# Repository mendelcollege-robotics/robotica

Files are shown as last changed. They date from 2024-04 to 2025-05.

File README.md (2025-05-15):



# About
This is the repository for all the files associated with, and used to create, a soccer robot for participation in the [Robocup](https://www.robocup.org/leagues/18). Made by students of the Mendelcollege, from team 'Mendel'.

# Info:

  [Mendelcollege.nl](https://mendelcollege.nl/ontdek-je-talenten/robotica-en-beta/)

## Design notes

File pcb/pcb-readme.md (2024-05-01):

 
teensy data from https://github.com/XenGi/teensy_library

created:
    l298n                   - https://www.kiwi-electronics.com/nl/dual-h-bridge-dc-stepper-motor-driver-l298n-4117?search=l293n
    pololu_motor            - https://www.pololu.com/product/4840
    tssp4038                - https://www.vishay.com/docs/82458/tssp40.pdf
    tcs3472_color_sensor    - https://www.biomaker.org/block-catalogue/2021/12/17/rgb-colour-sensor-tcs34725
    openmv_m7_r2            - https://openmv.io/products/openmv-cam-m7

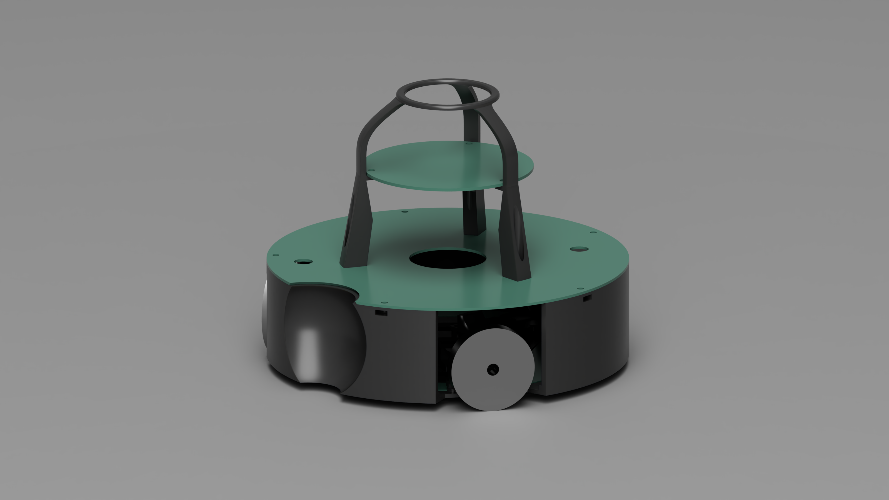
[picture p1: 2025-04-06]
3dfiles/Robot_V3.1_concept_2025-Apr-06_07-42-17PM-000_CustomizedView15199830637.png

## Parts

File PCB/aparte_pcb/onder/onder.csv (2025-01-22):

Id | Aanduiding | Footprint | Hoeveelheid | Orientatie | Leverancier en ref
1 | D11,D7,D9,D2,D5,D1,D10,D3,D8,D12,D4,D6 | LED_RGB_5050-6 | 12 | LED_RGB
2 | PR8,PR4,PR6,PR5,PR2,PR1,PR7,PR3 | FOTORESist | 8 | A1050
3 | 220Ω_36,220Ω_26,220Ω_33,220Ω_8,220Ω_23,220Ω_35,R2,220Ω_24,220Ω_27,220Ω_10,220Ω_4,220Ω_31,220Ω_12,220Ω_21,220Ω_2,10KΩ_4,220Ω_22,220Ω_20,220Ω_19,220Ω_15,220Ω_25,220Ω_17,R3,220Ω_34,10KΩ_6,220Ω_13,220Ω_28,220Ω_16,10KΩ_7,220Ω_7,10KΩ_5,10KΩ_1,220Ω_18,220Ω_6,220Ω_3,220Ω_5,10KΩ_3,220Ω_30,220Ω_11,10KΩ_8,R1,220Ω_14,10KΩ_2,220Ω_1,220Ω_9,220Ω_32,220Ω_29 | R_Axial_DIN0207_L6.3mm_D2.5mm_P10.16mm_Horizontal | 47 | R_US
4 | D13,D14 | D_MELF-RM10_Universal_Handsoldering | 2 | D
5 | J4,J3,J5 | MountingHole_4.3mm_M4_ISO7380_Pad | 3 | Screw_Terminal_01x01
6 | J2 | JST_EH_S10B-EH_1x10_P2.50mm_Horizontal | 1 | Conn_01x10_Socket
7 | Q1,Q3,Q2 | NPN | 3 | NPN
8 | J1 | JST_EH_S4B-EH_1x04_P2.50mm_Horizontal | 1 | Conn_01x04_Socket

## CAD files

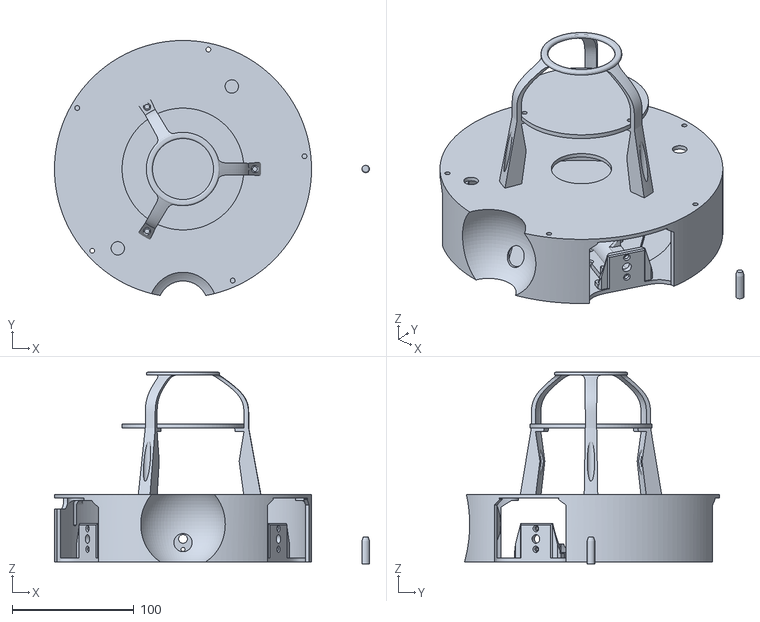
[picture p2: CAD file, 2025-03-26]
3dfiles/oud/Robotica Volledige Robot3 v35.stl
258.6 x 209.3 x 157.5

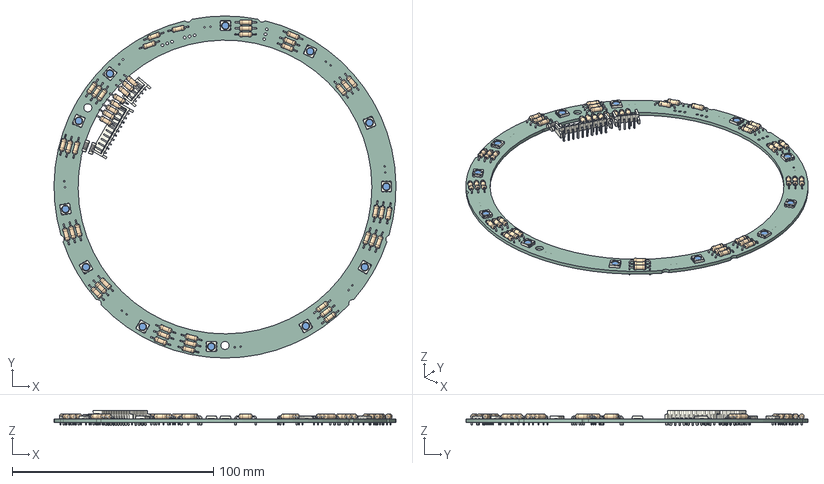
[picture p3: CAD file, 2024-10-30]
PCB/aparte_pcb/onder/onder.step
170.0 x 170.0 x 7.40 mm
LED_RGB_5050_6 x 12
R_Axial_DIN0207_L63mm_D25mm_P1016mm_Horizontal x 47
D_MELF_Standard x 2
JST_S10B_EH
JST_S4B_EH
_autosave-onder_PCB

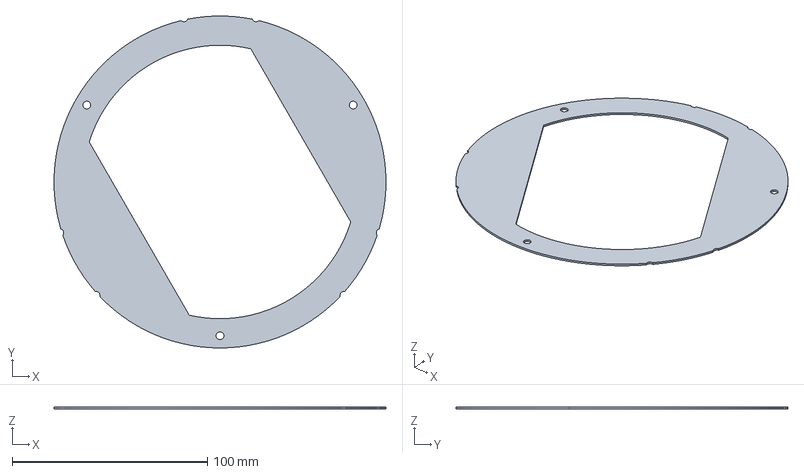
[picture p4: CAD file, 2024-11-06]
3dfiles/oud/PCBondermesh.3mf
170.0 x 170.0 x 1.00 mm

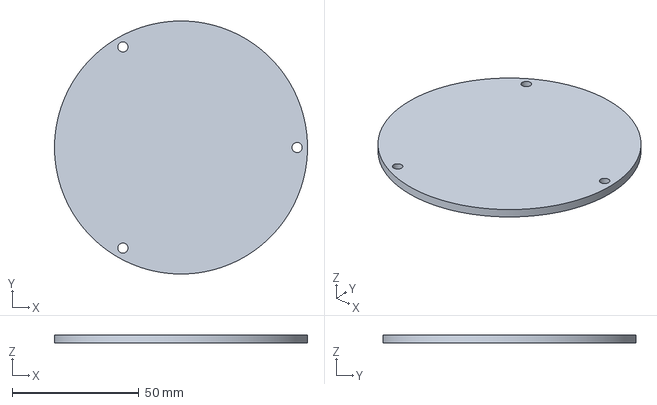
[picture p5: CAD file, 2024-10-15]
3dfiles/oud/PCBboven.3mf
100.0 x 100.0 x 3.25 mm

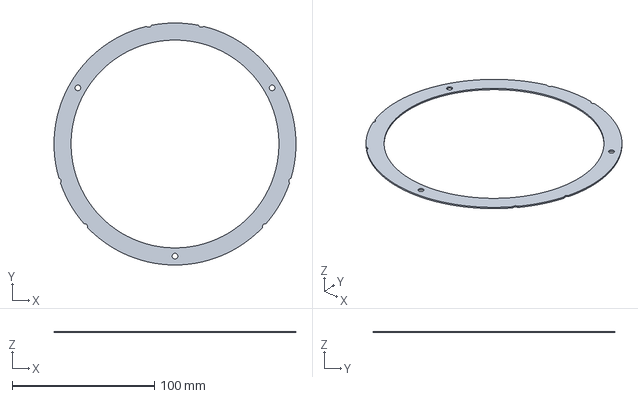
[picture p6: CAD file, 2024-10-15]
3dfiles/oud/PCBonder.3mf
170.0 x 170.0 x 1.00 mm

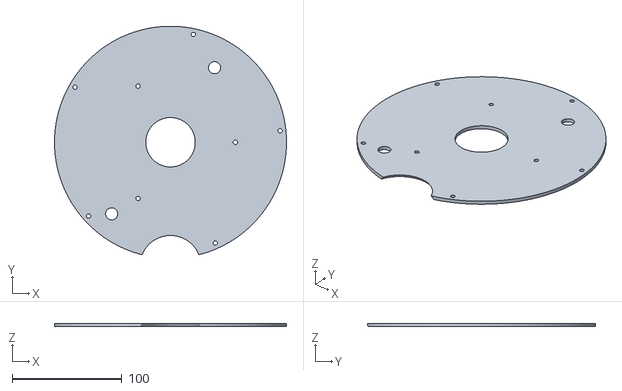
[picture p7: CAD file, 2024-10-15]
3dfiles/oud/PCBmidden.stl
211.0 x 207.8 x 3.00

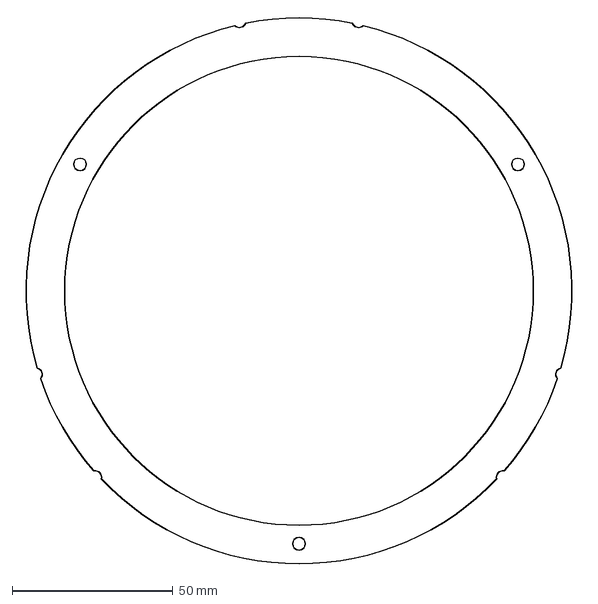
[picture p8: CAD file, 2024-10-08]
3dfiles/oud/pcb_onder(oud).dxf
176.2 x 170.5 mm

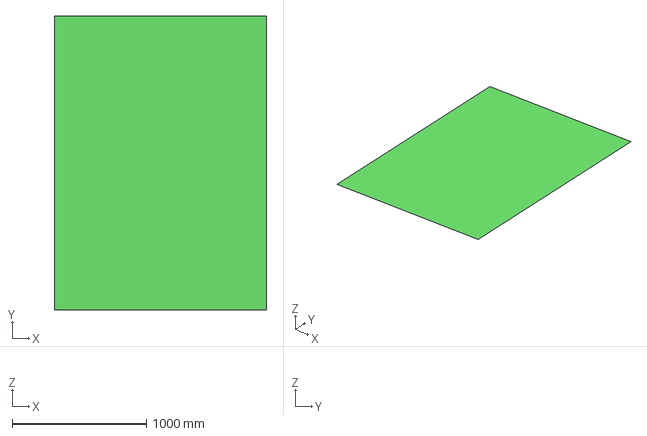
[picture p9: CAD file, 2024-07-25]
3dfiles/oud/feld.FCStd
1580.0 x 2190.0 x 0 mm

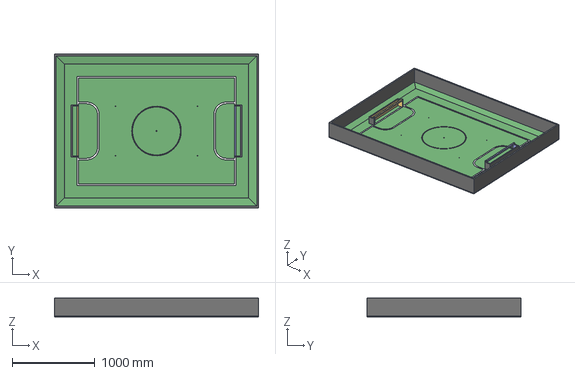
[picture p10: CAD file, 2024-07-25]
3dfiles/oud/RoboCupJunior SoccerField 2020.step
2470.0 x 1860.0 x 230.0 mm

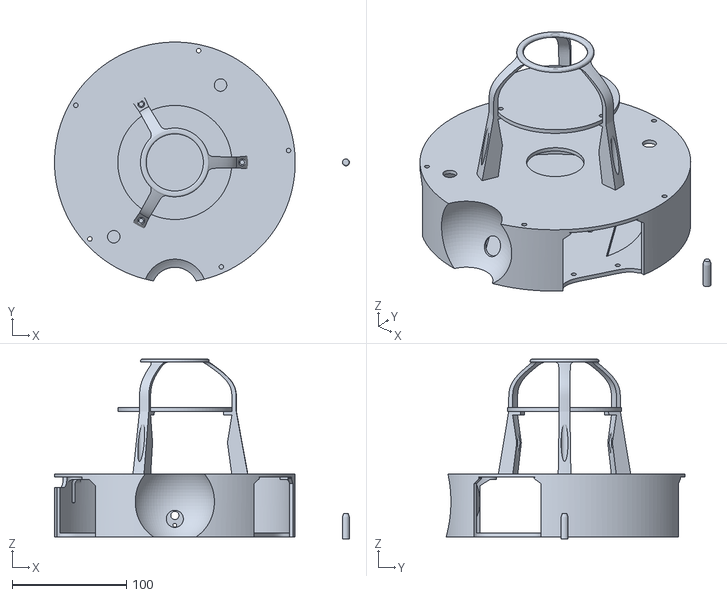
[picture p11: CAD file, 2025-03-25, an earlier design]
3dfiles/oud/Robotica Volledige Robot3 v29.stl
258.6 x 209.3 x 157.5

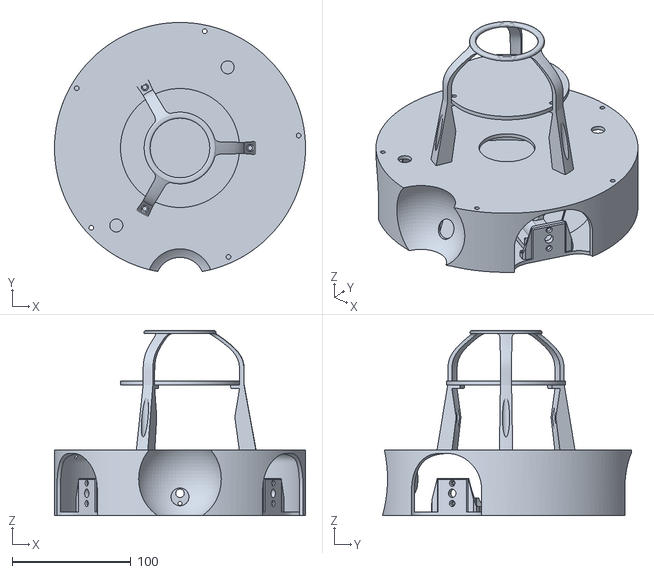
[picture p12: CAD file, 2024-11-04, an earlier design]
3dfiles/oud/Robotica Volledige Robot3 v18.stl
211.0 x 209.3 x 155.8

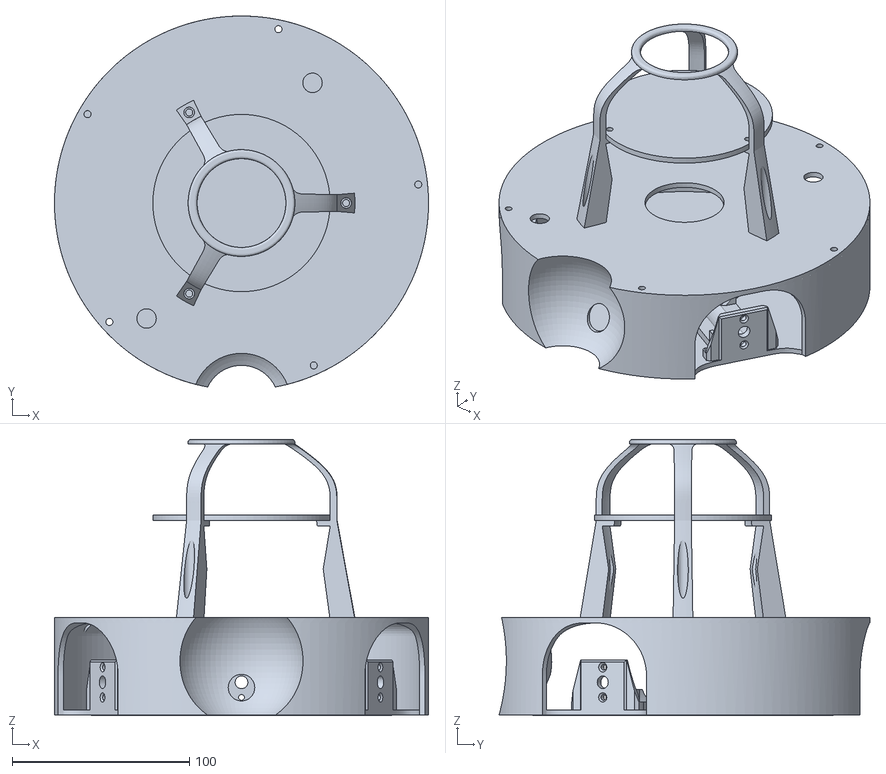
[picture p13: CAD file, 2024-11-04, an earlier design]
3dfiles/oud/Robotica Volledige Robot3 v17.stl
211.0 x 209.3 x 155.8

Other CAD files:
3dfiles/oud/soccerfield.obj
3dfiles/oud/Robotica Volledige Robot3 v16.stl
3dfiles/oud/Robotica Volledige Robot3 v15.stl
3dfiles/oud/PCBondermesh.stl
3dfiles/oud/Robotica Volledige Robot3 v11.f3z
3dfiles/oud/Robotica Volledige Robot3 v13.f3z
3dfiles/oud/Robotica Volledige Robot3 v15.f3z
3dfiles/oud/Robotica Volledige Robot3 v16.f3z
3dfiles/oud/Robotica Volledige Robot3 v17.f3z
3dfiles/oud/Robotica Volledige Robot3 v18.f3z
3dfiles/oud/Robotica Volledige Robot3 v29.f3z
3dfiles/oud/Robotica Volledige Robot3 v35.f3z
3dfiles/oud/Robotica Volledige Robot3 v5.f3z
3dfiles/oud/pcb_boven.dxf

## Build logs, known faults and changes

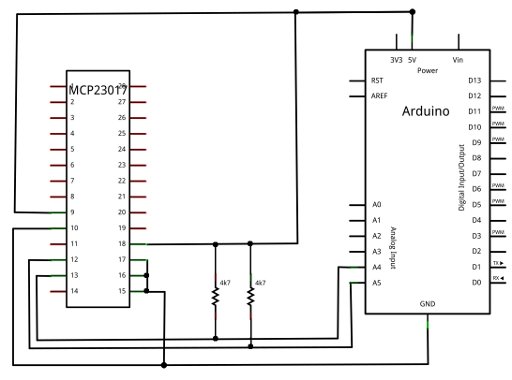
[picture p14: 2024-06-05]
CODE/debug/prewk/MCP23017/mcp20317_schemss.jpg

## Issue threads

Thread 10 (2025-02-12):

coderen

robosoccer, 2025-02-12:

robosoccer, 2025-02-26:
1. Motor drivers -- on/off -- 6 direction drive
2. comm tussen seeed-teensy
3. Led's controll+ foto res
4. IR sens
5. Comp
6. Cam

Closed 2025-03-20.

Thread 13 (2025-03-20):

PWM

ableTI, 2025-03-20:
add speed regulation to motors

ableTI, 2025-03-20:
also works it code, need to test in reel

ableTI, 2025-03-21:
tested via multimeter, updated code and works

Closed 2025-03-21.

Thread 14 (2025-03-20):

line detection

ableTI, 2025-03-20:
The LED are emmiting red led, add code to see white lines and make the robot react to it

ableTI, 2025-03-20:
analog ports arent used, use on/off via selected resistor

ableTI, 2025-03-20:
need to test but code done

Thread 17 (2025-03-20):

isolatie IR signaal

ableTI, 2025-03-20:
Zorg dat het alleen signaalen van voor de sensor krijgt, nu krijgt het zowat rondom signaalen.
https://4donline.ihs.com/images/VipMasterIC/IC/VISH/VISH-S-A0007978048/VISH-S-A0007978048-1.pdf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

ableTI, 2025-03-20:
aluminium tape

Closed 2025-03-20.

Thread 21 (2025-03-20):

Betere motor controller

ableTI, 2025-03-20:
Gebruik rpm counter en volledige 360 graden richting

ableTI, 2025-03-22:
Fix PWM

robosoccer, 2025-04-01:
SoftPWM.h werkt niet, ga weer zelf schijfen maar nu beter

ableTI, 2025-04-24:
PID moet goed

robosoccer, 2025-06-02:
Create a functioning PID inhttps://github.com/mendelcollege-robotics/robotica/blob/main/code/debug/motors/with-pid/with-pid.ino

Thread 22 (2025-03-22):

Serial comm

ableTI, 2025-03-22:
-het duurt ~2,5s tot data tussen seeed en teensy gestuurd word.
-2 seeeds op verschillende lijnen komen samen in een teensy serial port, geen idee hoe.

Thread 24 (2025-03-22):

Onder pcb ruimte fixen

ableTI, 2025-03-22:

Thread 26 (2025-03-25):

nieuwe wielen + barrel jack oplader

Jorns57, 2025-03-25:
wielen met frank enzo

robosoccer, 2025-03-27:
ook een teensy en twee seeed xiao

robosoccer, 2025-03-27:
https://gtfrobots.com/product/50mm-diameter-4mm-hole-size-omni-wheel/           6x

robosoccer, 2025-03-27:
https://www.tinytronics.nl/en/development-boards/microcontroller-boards/others/seeed-studio-seeeduino-xiao-cortex-m0-samd21 2x                                             https://www.tinytronics.nl/en/development-boards/microcontroller-boards/teensy/teensy-4.1-without-ethernet

Jorns57, 2025-03-30:
Barreljack oplader -> Jorn neemt mee vanuit huis

Jorns57, 2025-04-03:
Do 11-04 : wielen uit elkaar halen -> kwaliteit bepalen

robosoccer, 2025-04-04:
teensy, seeed's en openMV kabel zijn binnen gekomen

Jorns57, 2025-04-06:
ik heb thuis de juiste set screws (m4*~5mm) voor de wielen, die hoeven we dus niet te bestellen

Closed 2025-04-10.

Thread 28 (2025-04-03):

EK praktisch

Jorns57, 2025-04-03:
https://www.icjapigia1verga.it/robocupjunior/

-> Website nog niet af. Dus prijzen, hotels, slots en exacte data nog onbekend
- Mails sturen naar oa voetbal@robocupjunior.nl en wellicht roboticus voor duidelijkheid slots

Alle kosten (waaronder toegankskosten) moeten wij zelf onderverdelen. Ik (Jorn) rijd naar Italië van te voren (voor eigen vakantie) met zo veel mogelijk spullen, dus dat hoeft niet mee het vliegtuig in (of het vervoersmiddel dat andere mensen gebruiken). Het EK is van 4-7 Juni (week 23, week na hemelvaart)

Jorns57, 2025-04-06:
de mail die ik donderdag verstuurd heb is nog onbeantwoord, hopelijk voor aankomende donderdag antwoord

Closed 2025-05-22.

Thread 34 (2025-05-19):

Camera

Nathan220806, 2025-05-19:

Nathan220806, 2025-05-19:
openmv h7

ableTI, 2025-05-20:
Camera heeft al een issue, 'goal detection'.

Closed 2025-05-20.

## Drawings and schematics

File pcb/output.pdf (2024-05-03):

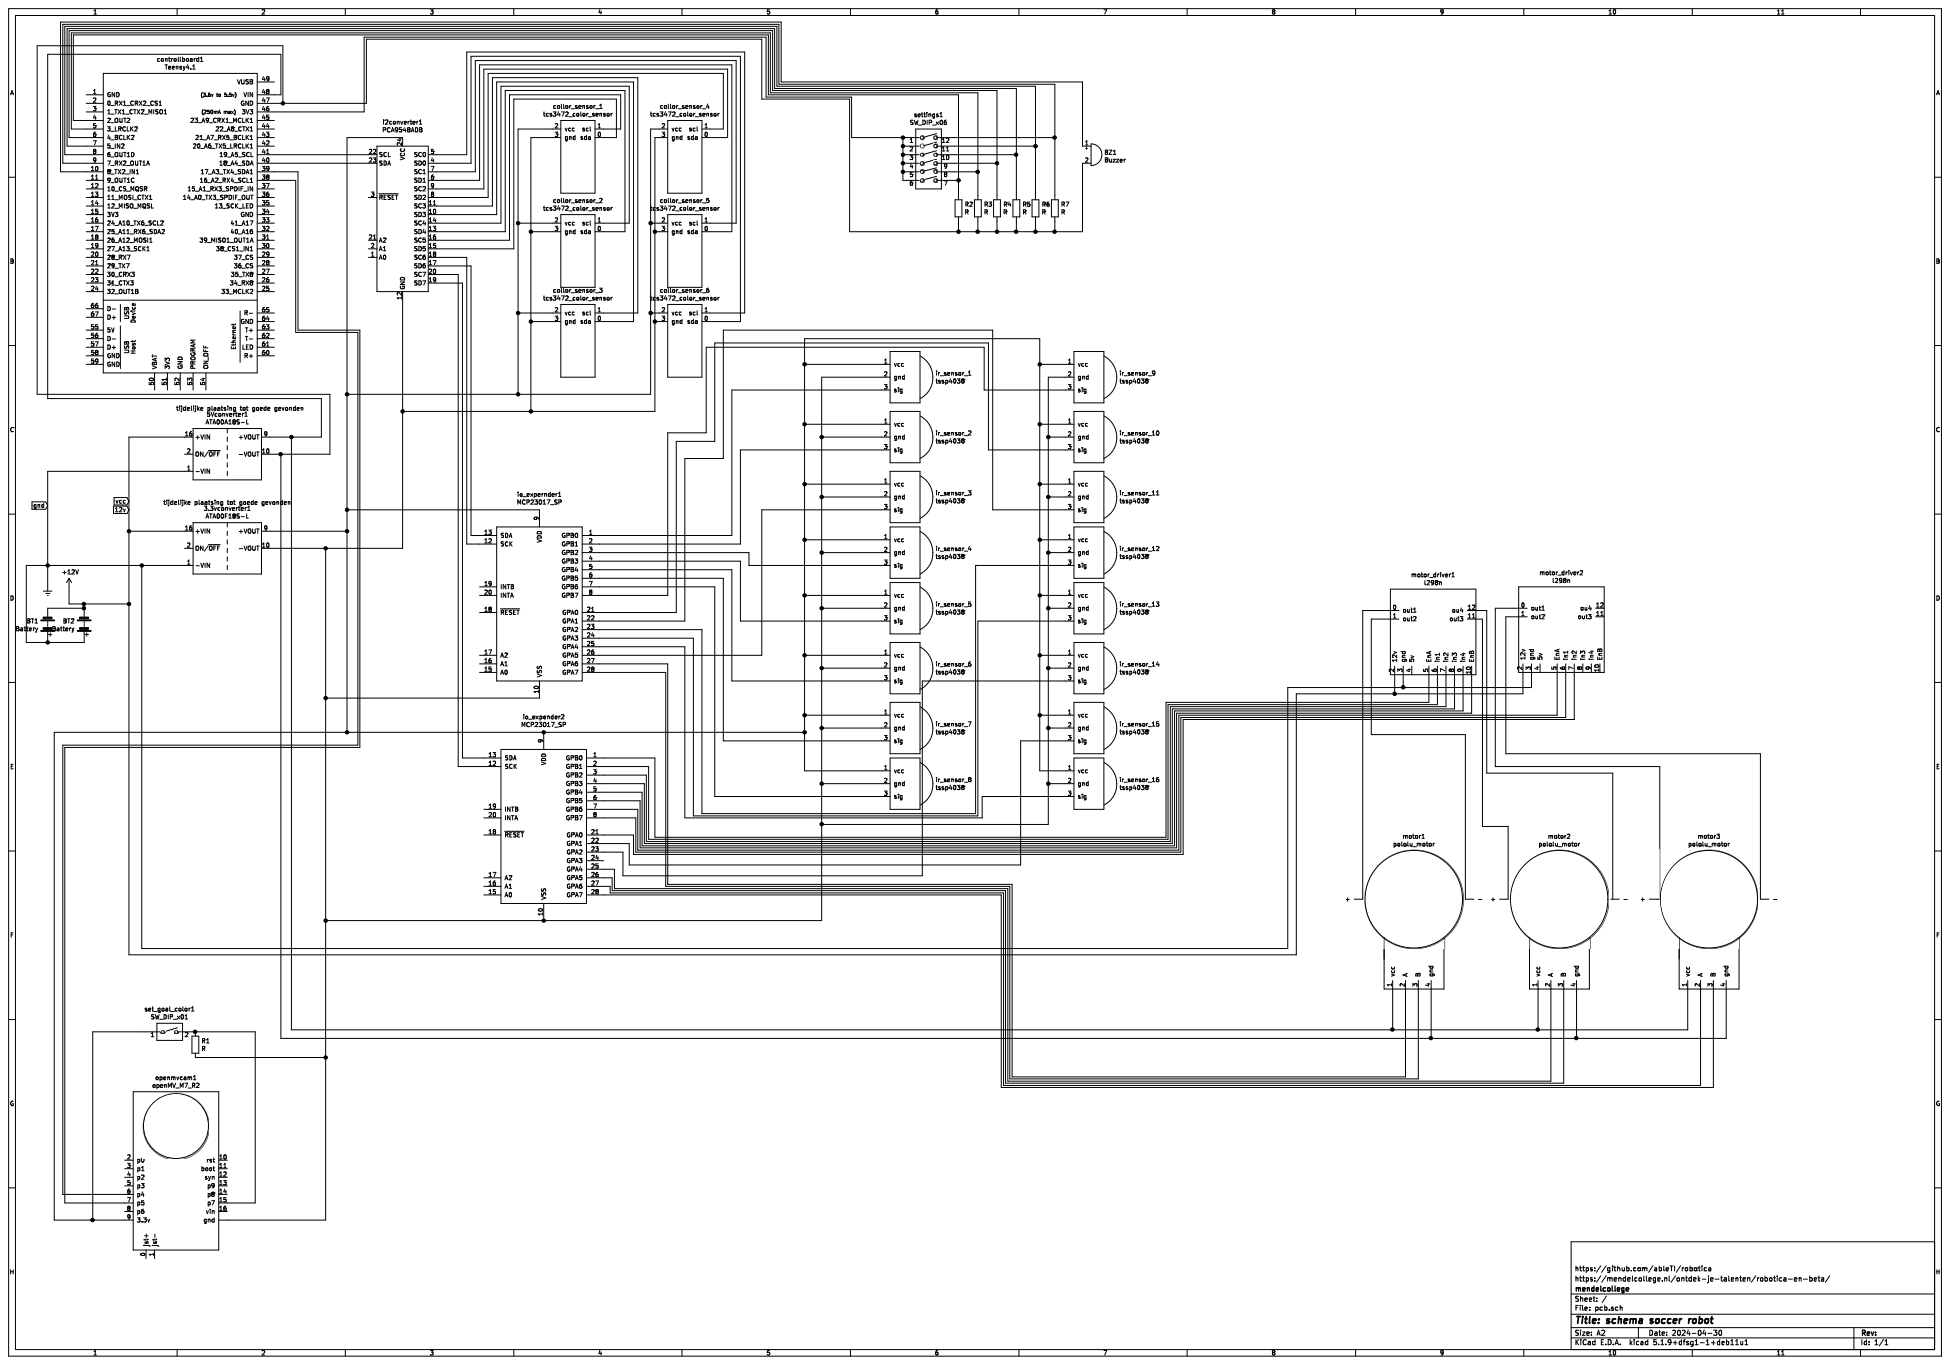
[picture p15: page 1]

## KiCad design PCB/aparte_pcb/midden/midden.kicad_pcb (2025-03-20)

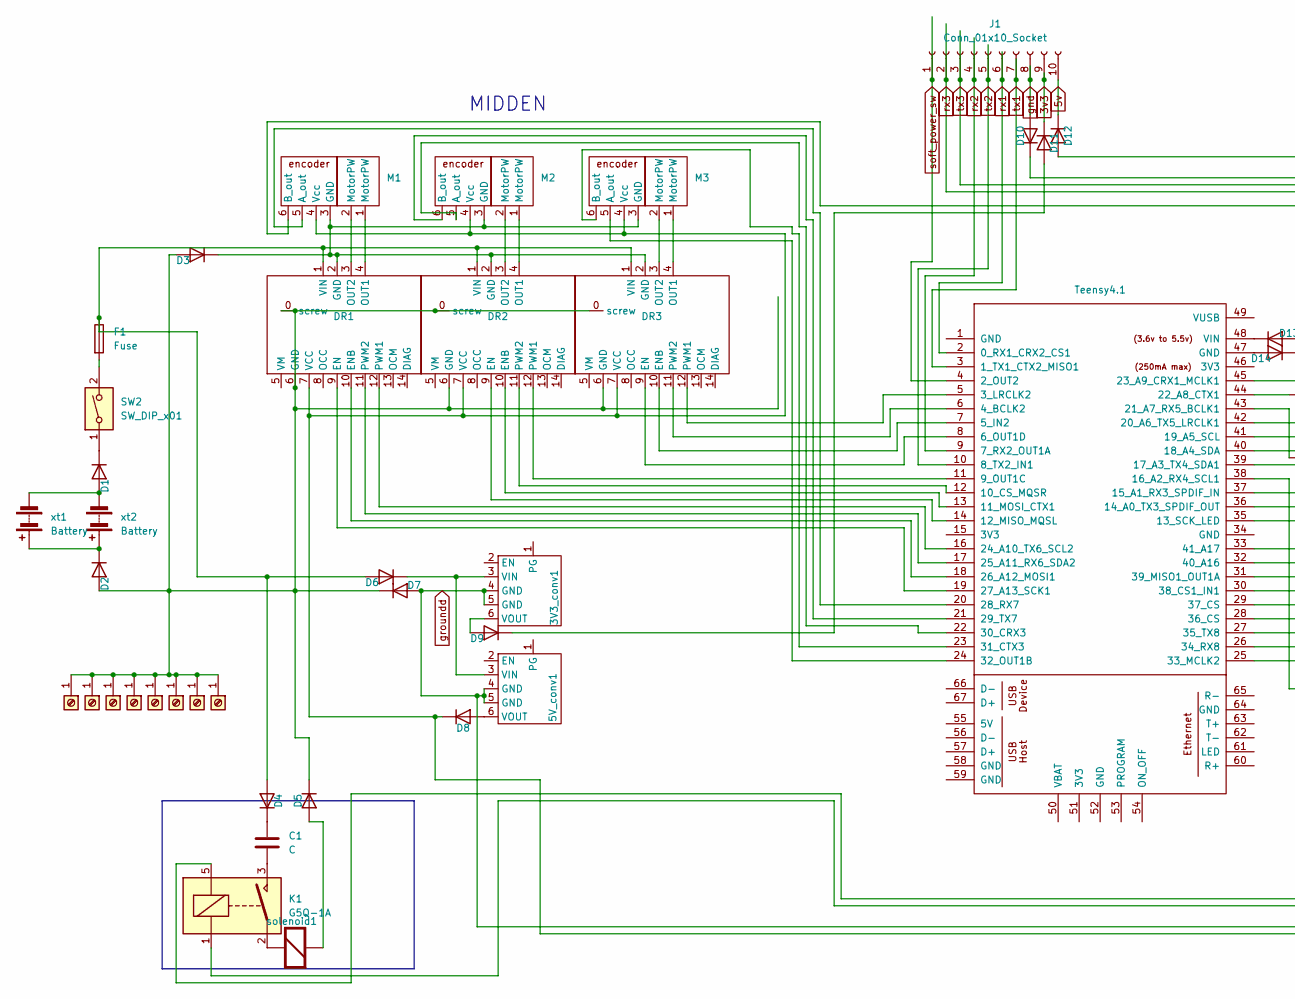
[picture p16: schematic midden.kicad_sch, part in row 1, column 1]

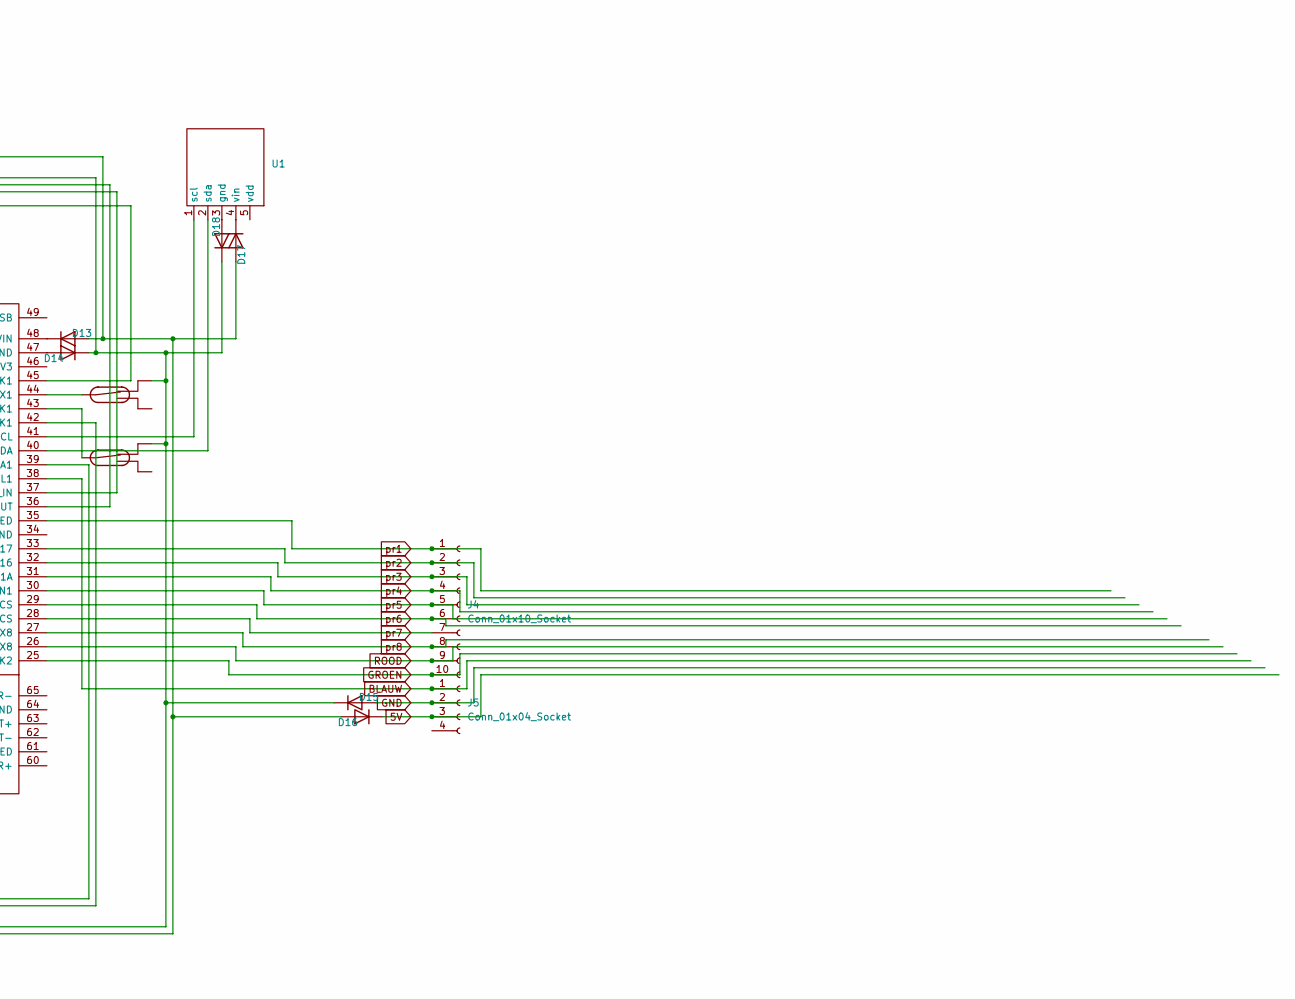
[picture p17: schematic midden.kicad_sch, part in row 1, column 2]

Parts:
3V3_conv1, 5V_conv1: pololu-d30v30fx
C1: C; CP_Radial_D8.0mm_P3.50mm
D1, D2, D3, D4, D5, D6, D7, D8, D9, D10, D11, D12, D13, D14, D15, D16, D17, D18: D; D_MELF-RM10_Universal_Handsoldering
DR1, DR2, DR3: TB9051FTG
F1: Fuse; Fuseholder_TR5_Littelfuse_No560_No460
J1, J4: Conn_01x10_Socket; JST_EH_S10B-EH_1x10_P2.50mm_Horizontal
J2, J3, J6, J7, J8, J9, J10, J11: Screw_Terminal_01x01; MountingHole_4.3mm_M4_ISO7380_Pad
J5: Conn_01x04_Socket; JST_EH_S4B-EH_1x04_P2.50mm_Horizontal
K1: G5Q-1A; Relay_SPST_Omron-G5Q-1A
M1, M2, M3: PinHeader_1x06_P1.27mm_Vertical
SW1, SW5: SW_Reed_SPDT; Mini Snap-Action Switch with 13.5mm Lever 3-Pin, SPDT, 1A
SW2: SW_DIP_x01; Rocker Switch 3-Pin, SPDT, 10A
U1: miniIMU
solenoid1: Re; Altech_AK100_1x02_P5.00mm; Rating V/Ω
teensy1: Teensy4.1; Teensy41
xt1: Battery; AMASS_XT60-F_1x02_P7.20mm_Vertical
xt2: Battery; AMASS_XT30U-M_1x02_P5.0mm_Vertical

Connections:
3v3: D11.1 (K), J1.9
5V: D16.1 (K), J5.3
5v: D12.1 (K), J1.10
BLAUW: J5.1, teensy1.38 (16_A2_RX4_SCL1)
GND: D15.2 (A), J5.2
GROEN: J4.10, teensy1.25 (33_MCLK2)
unnamed: 3V3_conv1.3 (VIN), 5V_conv1.3 (VIN), D6.1 (K)
unnamed: 3V3_conv1.6 (VOUT), D9.2 (A)
unnamed: 5V_conv1.6 (VOUT), D8.2 (A)
unnamed: C1.2, K1.3
unnamed: D1.2 (A), xt1.2 (-), xt2.2 (-)
unnamed: D1.1 (K), SW2.1
unnamed: D2.2 (A), D3.2 (A), D5.1 (K), D7.1 (K), DR1.0 (screw), DR1.6 (GND), DR2.0 (screw), DR2.6 (GND), DR3.0 (screw), DR3.6 (GND), J2.1, J3.1, J6.1, J7.1, J8.1, J9.1, J10.1, J11.1
unnamed: D2.1 (K), xt1.1 (+), xt2.1 (+)
unnamed: D3.1 (K), DR1.2 (GND), DR2.2 (GND), DR3.2 (GND), M1.3 (GND), M2.3 (GND), M3.3 (GND)
unnamed: D4.2 (A), D6.2 (A), DR1.1 (VIN), DR2.1 (VIN), DR3.1 (VIN), F1.1
unnamed: C1.1, D4.1 (K)
unnamed: D5.2 (A), solenoid1.2 (-)
unnamed: D9.1 (K), D11.2 (A)
unnamed: D8.1 (K), D12.2 (A), D13.2 (A), D16.2 (A), D17.2 (A), DR1.7 (VCC), DR2.7 (VCC), DR3.7 (VCC), M1.4 (Vcc), M2.4 (Vcc), M3.4 (Vcc)
unnamed: D13.1 (K), teensy1.48 (VIN)
unnamed: D14.2 (A), teensy1.47 (GND)
unnamed: D17.1 (K), U1.4 (vin)
unnamed: D18.2 (A), U1.3 (gnd)
unnamed: DR1.9 (EN), teensy1.19 (27_A13_SCK1)
unnamed: DR1.10 (ENB), teensy1.18 (26_A12_MOSI1)
unnamed: DR1.4 (OUT1), M1.1 (MotorPW)
unnamed: DR1.3 (OUT2), M1.2 (MotorPW)
unnamed: DR1.12 (PWM1), teensy1.16 (24_A10_TX6_SCL2)
unnamed: DR1.11 (PWM2), teensy1.17 (25_A11_RX6_SDA2)
unnamed: DR2.9 (EN), teensy1.14 (12_MISO_MQSL)
unnamed: DR2.10 (ENB), teensy1.13 (11_MOSI_CTX1)
unnamed: DR2.4 (OUT1), M2.1 (MotorPW)
unnamed: DR2.3 (OUT2), M2.2 (MotorPW)
unnamed: DR2.12 (PWM1), teensy1.11 (9_OUT1C)
unnamed: DR2.11 (PWM2), teensy1.12 (10_CS_MQSR)
unnamed: DR3.9 (EN), teensy1.8 (6_OUT1D)
unnamed: DR3.10 (ENB), teensy1.7 (5_IN2)
unnamed: DR3.4 (OUT1), M3.1 (MotorPW)
unnamed: DR3.3 (OUT2), M3.2 (MotorPW)
unnamed: DR3.12 (PWM1), teensy1.5 (3_LRCLK2)
unnamed: DR3.11 (PWM2), teensy1.6 (4_BCLK2)
unnamed: F1.2, SW2.2
unnamed: M1.5 (A_out), teensy1.20 (28_RX7)
unnamed: M1.6 (B_out), teensy1.45 (23_A9_CRX1_MCLK1)
unnamed: M2.5 (A_out), teensy1.22 (30_CRX3)
unnamed: M2.6 (B_out), teensy1.21 (29_TX7)
unnamed: M3.5 (A_out), teensy1.24 (32_OUT1B)
unnamed: M3.6 (B_out), teensy1.23 (31_CTX3)
unnamed: U1.1 (scl), teensy1.41 (19_A5_SCL)
unnamed: U1.2 (sda), teensy1.40 (18_A4_SDA)
unnamed: K1.2, solenoid1.1 (+)
unnamed: K1.5, teensy1.39 (17_A3_TX4_SDA1)
unnamed: K1.1, teensy1.42 (20_A6_TX5_LRCLK1)
unnamed: SW5.2, teensy1.43 (21_A7_RX5_BCLK1)
unnamed: SW1.2, teensy1.44 (22_A8_CTX1)
ROOD: J4.9, teensy1.26 (34_RX8)
gnd: D10.2 (A), J1.8
groundd: 3V3_conv1.4 (GND), 3V3_conv1.5 (GND), 5V_conv1.4 (GND), 5V_conv1.5 (GND), D7.2 (A), D10.1 (K), D14.1 (K), D15.1 (K), D18.1 (K), SW1.1, SW5.1
pr1: J4.1, teensy1.35 (13_SCK_LED)
pr2: J4.2, teensy1.33 (41_A17)
pr3: J4.3, teensy1.32 (40_A16)
pr4: J4.4, teensy1.31 (39_MISO1_OUT1A)
pr5: J4.5, teensy1.30 (38_CS1_IN1)
pr6: J4.6, teensy1.29 (37_CS)
pr7: J4.7, teensy1.28 (36_CS)
pr8: J4.8, teensy1.27 (35_TX8)
rx1: J1.6, teensy1.2 (0_RX1_CRX2_CS1)
rx2: J1.4, teensy1.9 (7_RX2_OUT1A)
rx3: J1.2, teensy1.37 (15_A1_RX3_SPDIF_IN)
soft_power_sw: J1.1, teensy1.4 (2_OUT2)
tx1: J1.7, teensy1.3 (1_TX1_CTX2_MISO1)
tx2: J1.5, teensy1.10 (8_TX2_IN1)
tx3: J1.3, teensy1.36 (14_A0_TX3_SPDIF_OUT)

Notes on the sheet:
MIDDEN

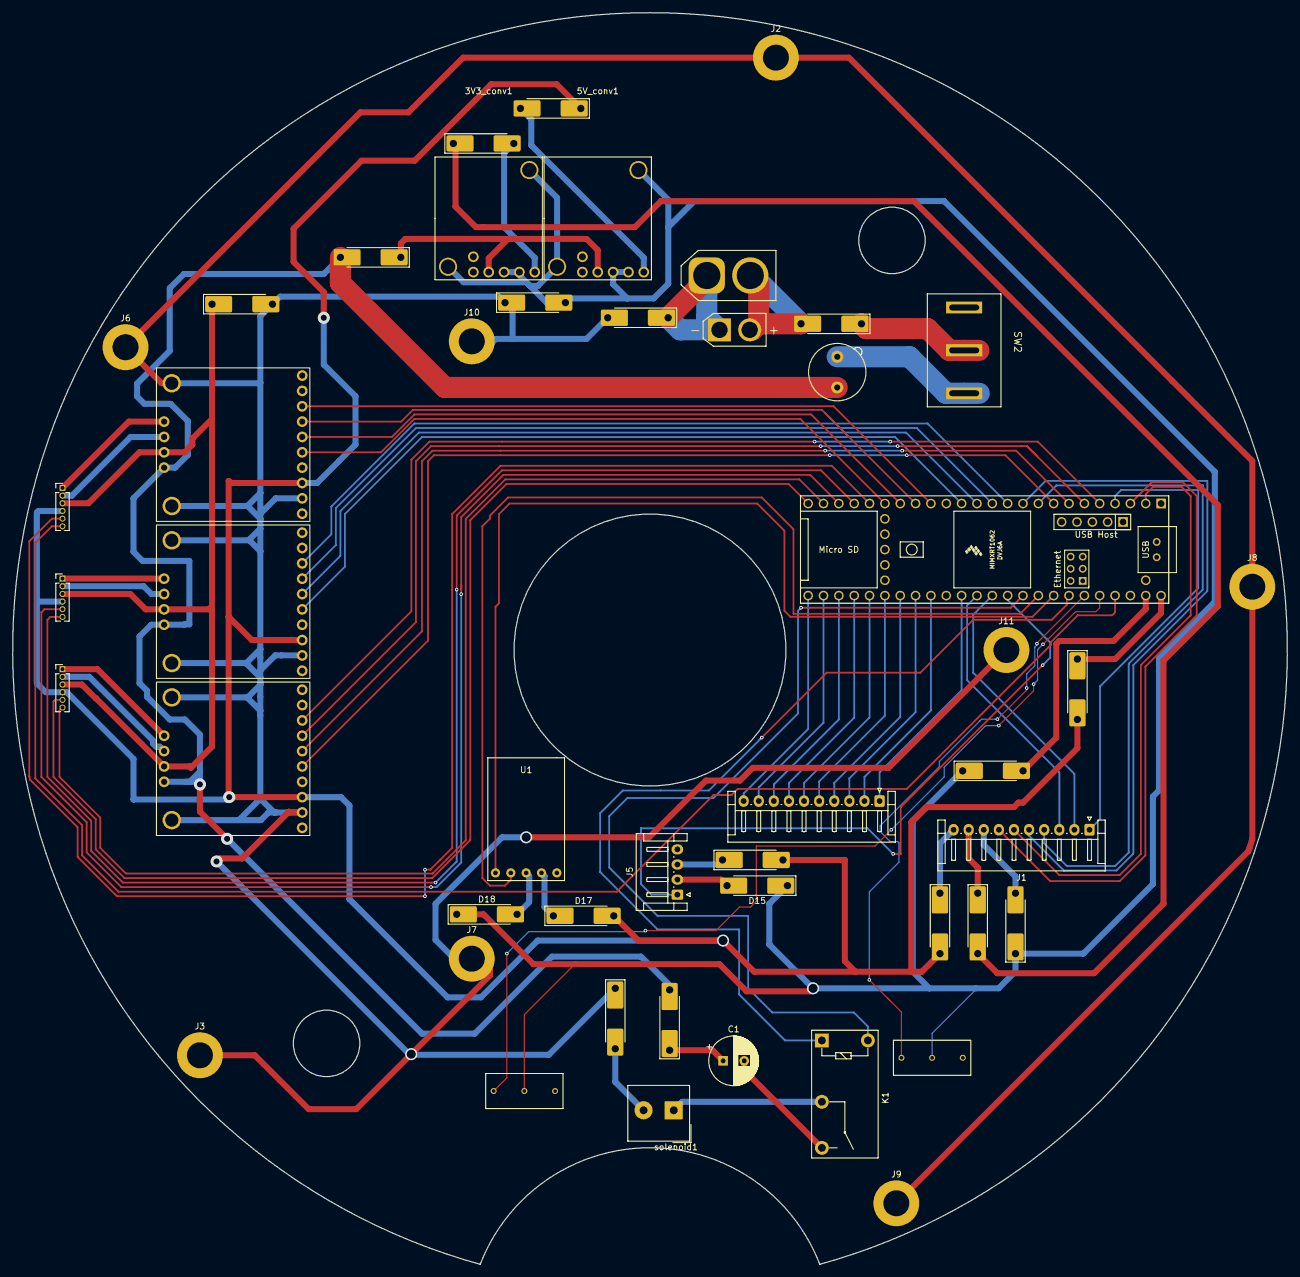
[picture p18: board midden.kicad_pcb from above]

Board: 2 copper layers, 211.0 x 207.2 mm, 48 parts (0 on the bottom side), 74 nets.

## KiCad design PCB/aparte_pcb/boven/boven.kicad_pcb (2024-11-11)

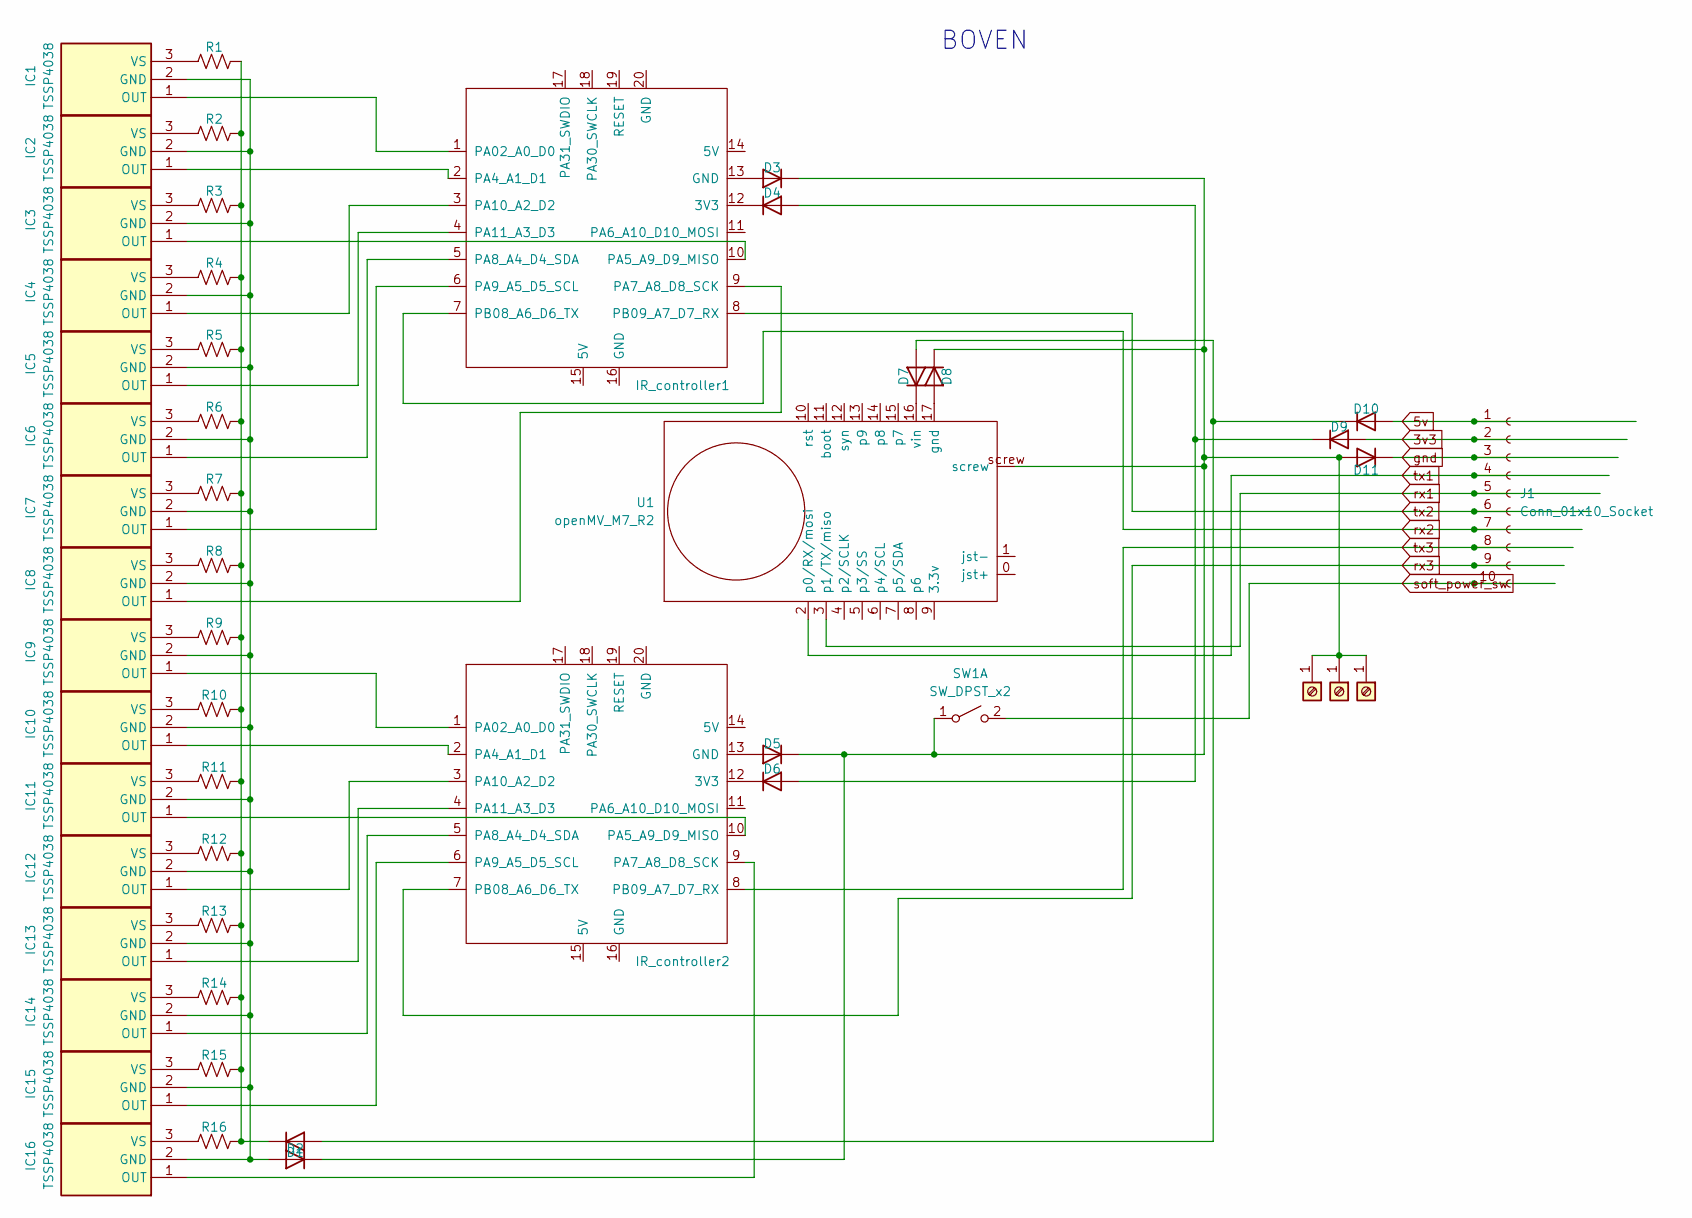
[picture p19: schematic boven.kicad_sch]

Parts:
D1, D2, D3, D4, D5, D6, D7, D8, D9, D10, D11: D; D_MELF-RM10_Universal_Handsoldering
IC1, IC2, IC3, IC4, IC5, IC6, IC7, IC8, IC9, IC10, IC11, IC12, IC13, IC14, IC15, IC16: TSSP4038; Manufacturer_Part_Number TSSP4038; Mouser Part Number 782-TSSP4038
IR_controller1, IR_controller2: Seeed Studio XIAO SAMD21; Seeduino Xiao Kicad af
J1: Conn_01x10_Socket; JST_EH_S10B-EH_1x10_P2.50mm_Horizontal
J2: Screw_Terminal_01x01; MountingHole_4.3mm_M4_DIN965_Pad
J3, J4: Screw_Terminal_01x01; MountingHole_4.3mm_M4_ISO7380_Pad
R1, R2, R3, R4, R5, R6, R7, R8, R9, R10, R11, R12, R13, R14, R15, R16: R_US; R_Axial_DIN0207_L6.3mm_D2.5mm_P10.16mm_Horizontal
SW1: SW_DPST_x2; R1966ABLKBLKEF
U1: openMV_M7_R2; openmv_m7_r2

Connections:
3v3: D9.2 (A), J1.2
5v: D10.2 (A), J1.1
unnamed: D1.2 (A), D7.2 (A), D10.1 (K)
unnamed: D1.1 (K), R1.2, R2.2, R3.2, R4.2, R5.2, R6.2, R7.2, R8.2, R9.2, R10.2, R11.2, R12.2, R13.2, R14.2, R15.2, R16.2
unnamed: D2.2 (A), IC1.2 (GND), IC2.2 (GND), IC3.2 (GND), IC4.2 (GND), IC5.2 (GND), IC6.2 (GND), IC7.2 (GND), IC8.2 (GND), IC9.2 (GND), IC10.2 (GND), IC11.2 (GND), IC12.2 (GND), IC13.2 (GND), IC14.2 (GND), IC15.2 (GND), IC16.2 (GND)
unnamed: D3.2 (A), IR_controller1.13 (GND)
unnamed: D4.2 (A), D6.2 (A), D9.1 (K)
unnamed: D4.1 (K), IR_controller1.12 (3V3)
unnamed: D5.2 (A), IR_controller2.13 (GND)
unnamed: D6.1 (K), IR_controller2.12 (3V3)
unnamed: D7.1 (K), U1.16 (vin)
unnamed: D8.2 (A), U1.17 (gnd)
unnamed: D2.1 (K), D3.1 (K), D5.1 (K), D8.1 (K), D11.2 (A), J2.1, J3.1, J4.1, SW1.1 (A), U1.screw
unnamed: IC1.1 (OUT), IR_controller1.1 (PA02_A0_D0)
unnamed: IC1.3 (VS), R1.1
unnamed: IC2.1 (OUT), IR_controller1.2 (PA4_A1_D1)
unnamed: IC2.3 (VS), R2.1
unnamed: IC3.1 (OUT), IR_controller1.10 (PA5_A9_D9_MISO)
unnamed: IC3.3 (VS), R3.1
unnamed: IC4.1 (OUT), IR_controller1.3 (PA10_A2_D2)
unnamed: IC4.3 (VS), R4.1
unnamed: IC5.1 (OUT), IR_controller1.4 (PA11_A3_D3)
unnamed: IC5.3 (VS), R5.1
unnamed: IC6.1 (OUT), IR_controller1.5 (PA8_A4_D4_SDA)
unnamed: IC6.3 (VS), R6.1
unnamed: IC7.1 (OUT), IR_controller1.6 (PA9_A5_D5_SCL)
unnamed: IC7.3 (VS), R7.1
unnamed: IC8.1 (OUT), IR_controller1.9 (PA7_A8_D8_SCK)
unnamed: IC8.3 (VS), R8.1
unnamed: IC9.1 (OUT), IR_controller2.1 (PA02_A0_D0)
unnamed: IC9.3 (VS), R9.1
unnamed: IC10.1 (OUT), IR_controller2.2 (PA4_A1_D1)
unnamed: IC10.3 (VS), R10.1
unnamed: IC11.1 (OUT), IR_controller2.10 (PA5_A9_D9_MISO)
unnamed: IC11.3 (VS), R11.1
unnamed: IC12.1 (OUT), IR_controller2.3 (PA10_A2_D2)
unnamed: IC12.3 (VS), R12.1
unnamed: IC13.1 (OUT), IR_controller2.4 (PA11_A3_D3)
unnamed: IC13.3 (VS), R13.1
unnamed: IC14.1 (OUT), IR_controller2.5 (PA8_A4_D4_SDA)
unnamed: IC14.3 (VS), R14.1
unnamed: IC15.1 (OUT), IR_controller2.6 (PA9_A5_D5_SCL)
unnamed: IC15.3 (VS), R15.1
unnamed: IC16.1 (OUT), IR_controller2.9 (PA7_A8_D8_SCK)
unnamed: IC16.3 (VS), R16.1
gnd: D11.1 (K), J1.3
rx1: J1.5, U1.3 (p1/TX/miso)
rx2: IR_controller1.7 (PB08_A6_D6_TX), J1.7
rx3: IR_controller2.7 (PB08_A6_D6_TX), J1.9
soft_power_sw: J1.10, SW1.2 (B)
tx1: J1.4, U1.2 (p0/RX/mosi)
tx2: IR_controller1.8 (PB09_A7_D7_RX), J1.6
tx3: IR_controller2.8 (PB09_A7_D7_RX), J1.8

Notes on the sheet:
BOVEN

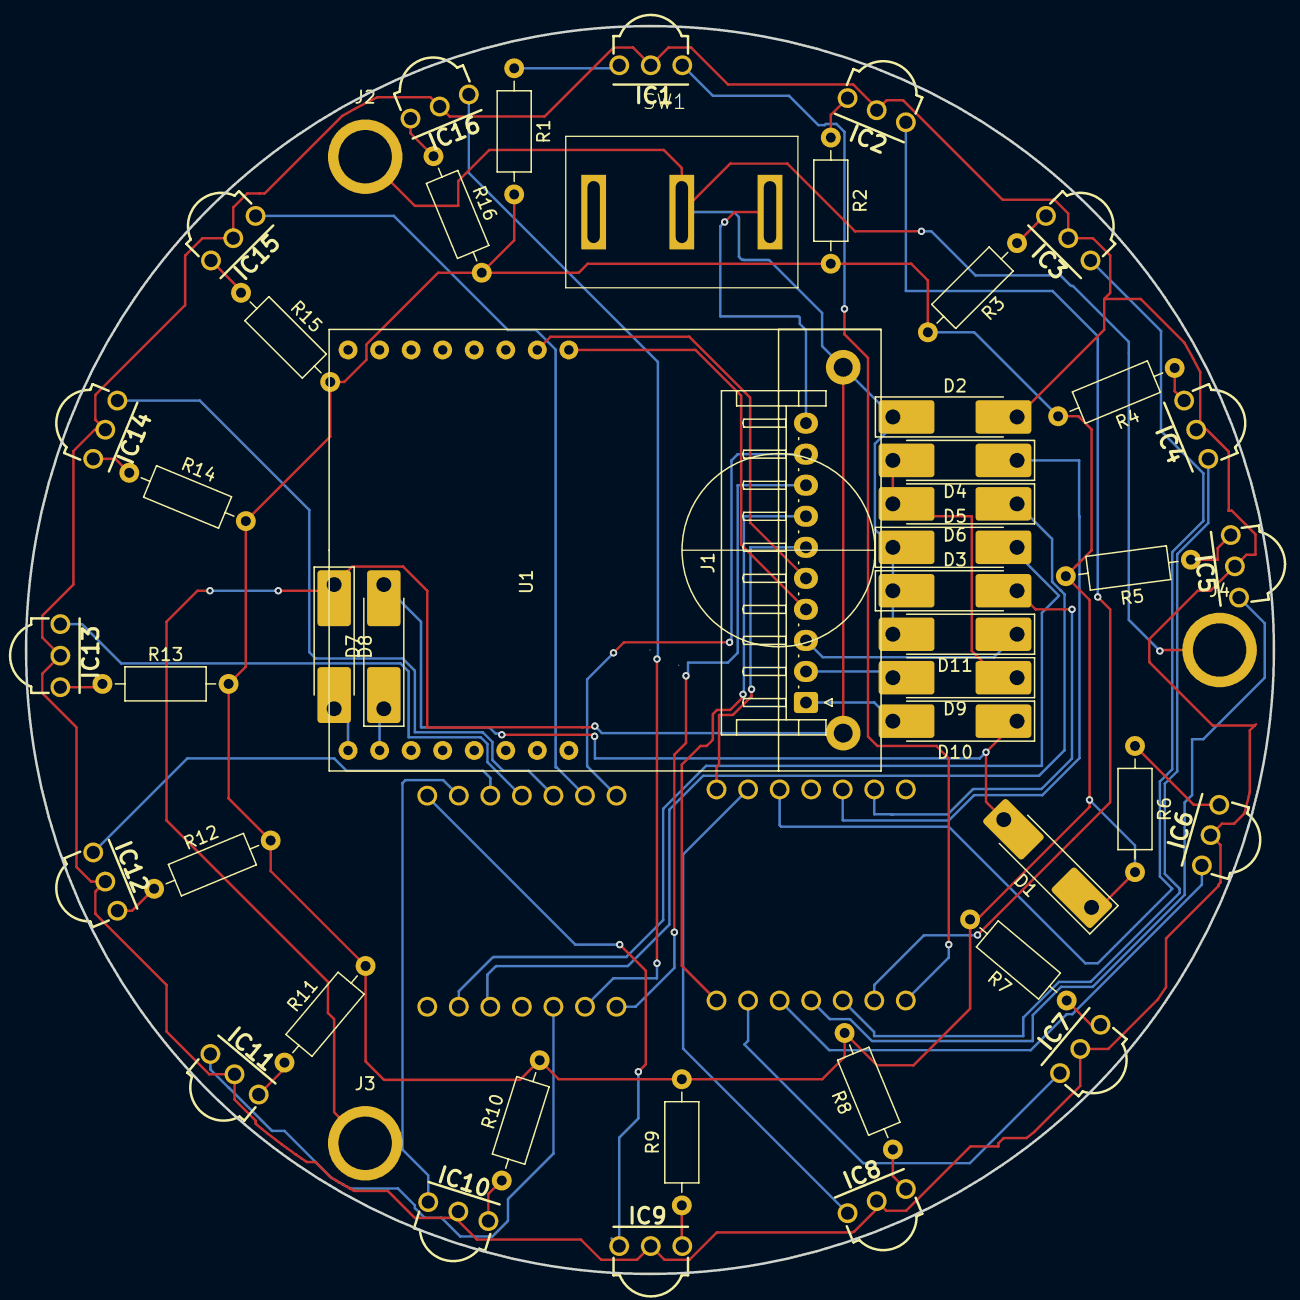
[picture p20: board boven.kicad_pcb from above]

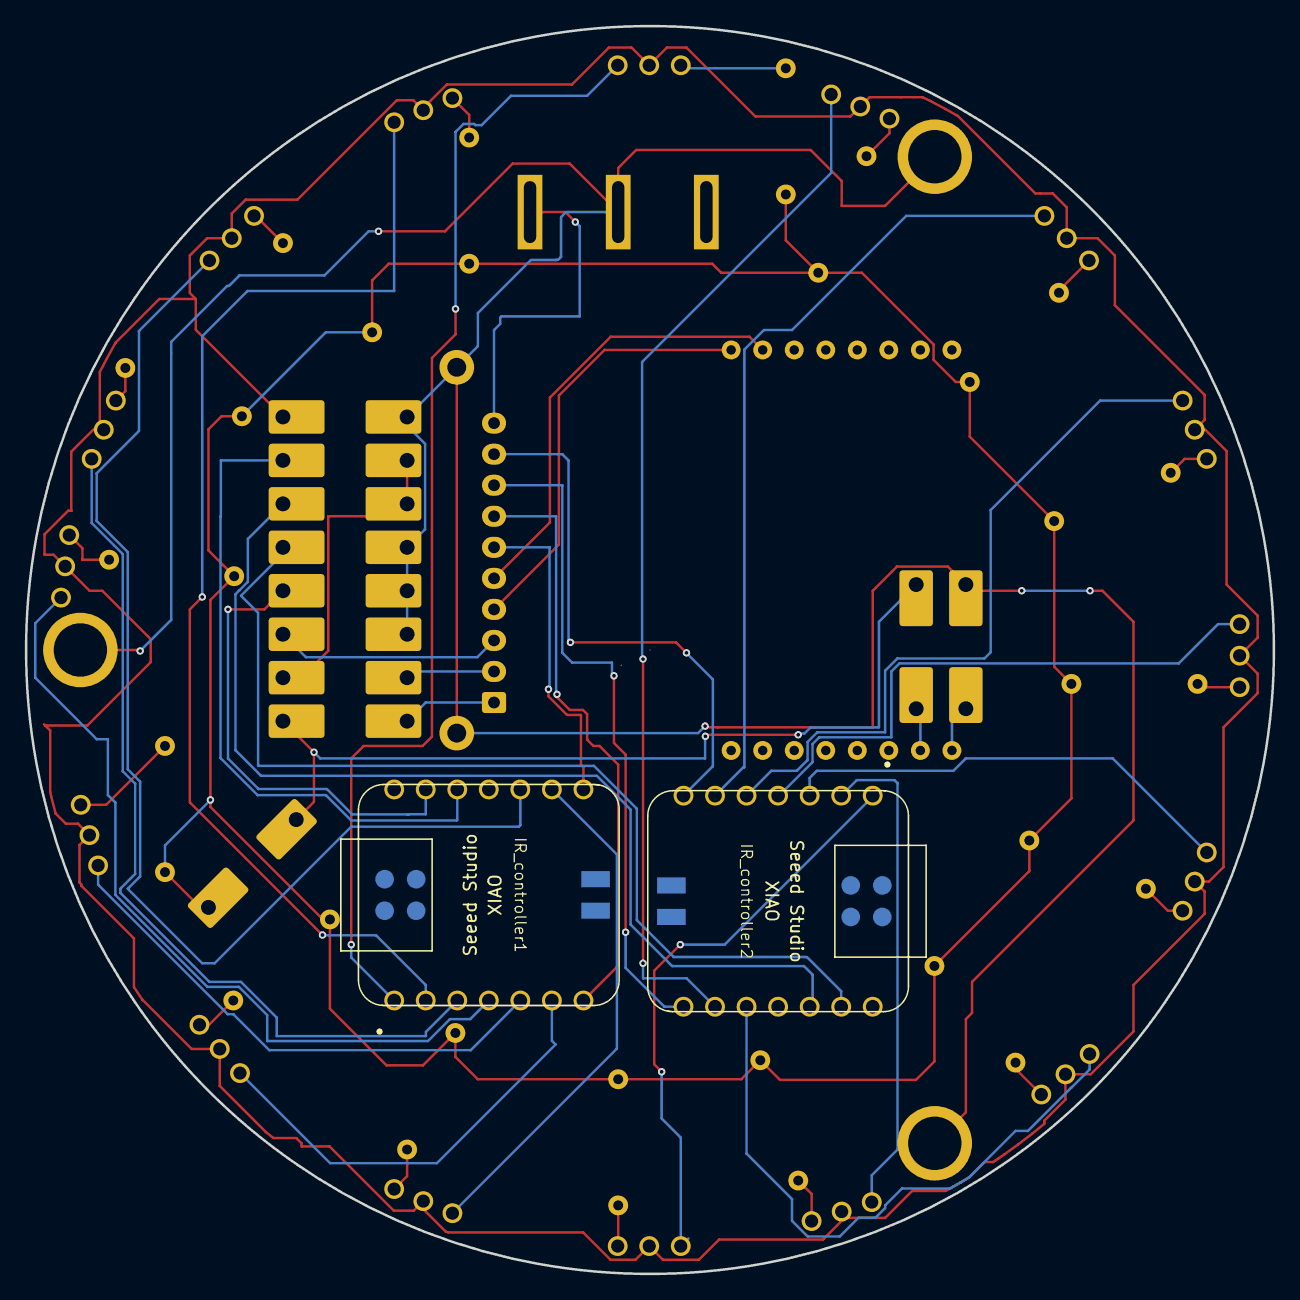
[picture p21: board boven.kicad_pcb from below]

Board: 2 copper layers, 100.5 x 100.5 mm, 51 parts (2 on the bottom side), 53 nets.

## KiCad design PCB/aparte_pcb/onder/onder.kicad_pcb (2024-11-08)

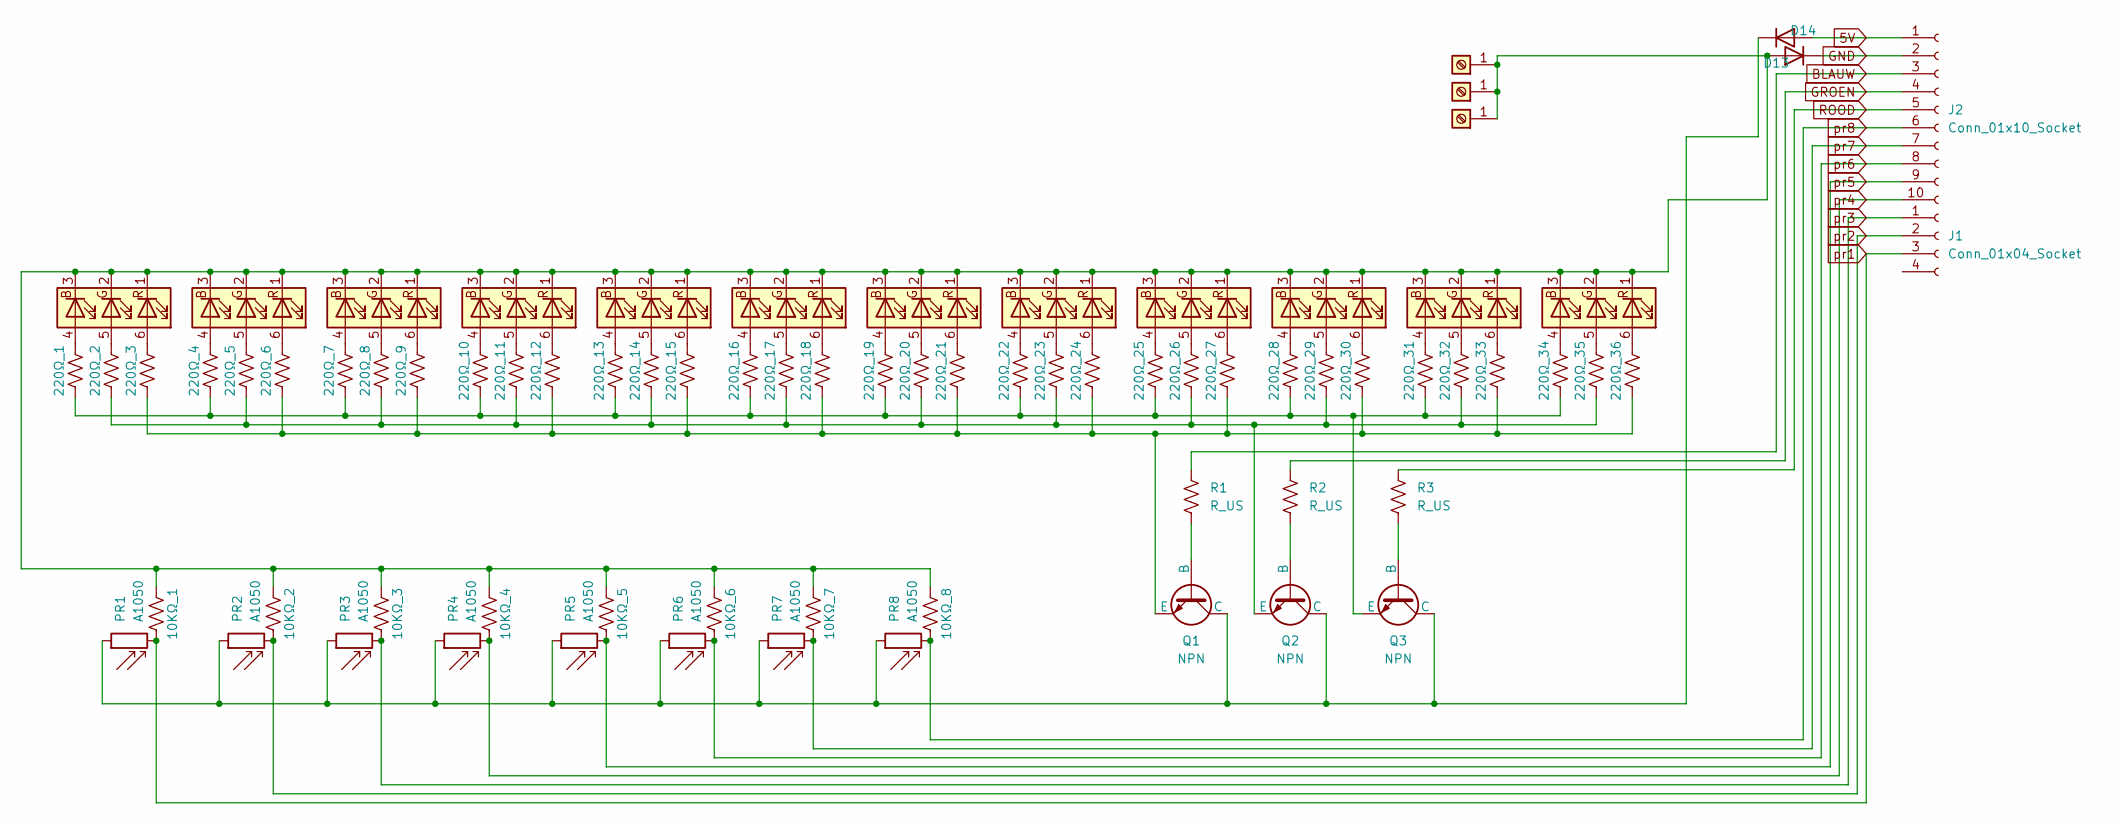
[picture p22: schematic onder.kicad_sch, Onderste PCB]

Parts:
10KΩ_1, 10KΩ_2, 10KΩ_3, 10KΩ_4, 10KΩ_5, 10KΩ_6, 10KΩ_7, 10KΩ_8, 220Ω_1, 220Ω_2, 220Ω_3, 220Ω_4, 220Ω_5, 220Ω_6, 220Ω_7, 220Ω_8, 220Ω_9, 220Ω_10, 220Ω_11, 220Ω_12, 220Ω_13, 220Ω_14, 220Ω_15, 220Ω_16, 220Ω_17, 220Ω_18, 220Ω_19, 220Ω_20, 220Ω_21, 220Ω_22, 220Ω_23, 220Ω_24, 220Ω_25, 220Ω_26, 220Ω_27, 220Ω_28, 220Ω_29, 220Ω_30, 220Ω_31, 220Ω_32, 220Ω_33, 220Ω_34, 220Ω_35, 220Ω_36: R_US; R_Axial_DIN0207_L6.3mm_D2.5mm_P10.16mm_Horizontal
D1, D2, D3, D4, D5, D6, D7, D8, D9, D10, D11, D12: LED_RGB; LED_RGB_5050-6
D13, D14: D; D_MELF-RM10_Universal_Handsoldering
J1: Conn_01x04_Socket; JST_EH_S4B-EH_1x04_P2.50mm_Horizontal
J2: Conn_01x10_Socket; JST_EH_S10B-EH_1x10_P2.50mm_Horizontal
J3, J4, J5: Screw_Terminal_01x01; MountingHole_4.3mm_M4_ISO7380_Pad
PR1, PR2, PR3, PR4, PR5, PR6, PR7, PR8: A1050; FOTORESist
Q1, Q2, Q3: NPN
R1, R2, R3: R_US; R_Axial_DIN0207_L6.3mm_D2.5mm_P10.16mm_Horizontal

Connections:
5V: D14.2 (A), J2.1
BLAUW: J2.3, R1.2
GND: D13.1 (K), J2.2
GROEN: J2.4, R2.2
unnamed: 220Ω_1.1, D1.4 (BA)
unnamed: 10KΩ_1.2, 10KΩ_2.2, 10KΩ_3.2, 10KΩ_4.2, 10KΩ_5.2, 10KΩ_6.2, 10KΩ_7.2, 10KΩ_8.2, D1.1 (RK), D1.2 (GK), D1.3 (BK), D2.1 (RK), D2.2 (GK), D2.3 (BK), D3.1 (RK), D3.2 (GK), D3.3 (BK), D4.1 (RK), D4.2 (GK), D4.3 (BK), D5.1 (RK), D5.2 (GK), D5.3 (BK), D6.1 (RK), D6.2 (GK), D6.3 (BK), D7.1 (RK), D7.2 (GK), D7.3 (BK), D8.1 (RK), D8.2 (GK), D8.3 (BK), D9.1 (RK), D9.2 (GK), D9.3 (BK), D10.1 (RK), D10.2 (GK), D10.3 (BK), D11.1 (RK), D11.2 (GK), D11.3 (BK), D12.1 (RK), D12.2 (GK), D12.3 (BK), D13.2 (A), J3.1, J4.1, J5.1
unnamed: 220Ω_2.1, D1.5 (GA)
unnamed: 220Ω_3.1, D1.6 (RA)
unnamed: 220Ω_4.1, D2.4 (BA)
unnamed: 220Ω_5.1, D2.5 (GA)
unnamed: 220Ω_6.1, D2.6 (RA)
unnamed: 220Ω_7.1, D3.4 (BA)
unnamed: 220Ω_8.1, D3.5 (GA)
unnamed: 220Ω_9.1, D3.6 (RA)
unnamed: 220Ω_10.1, D4.4 (BA)
unnamed: 220Ω_11.1, D4.5 (GA)
unnamed: 220Ω_12.1, D4.6 (RA)
unnamed: 220Ω_13.1, D5.4 (BA)
unnamed: 220Ω_14.1, D5.5 (GA)
unnamed: 220Ω_15.1, D5.6 (RA)
unnamed: 220Ω_16.1, D6.4 (BA)
unnamed: 220Ω_17.1, D6.5 (GA)
unnamed: 220Ω_18.1, D6.6 (RA)
unnamed: 220Ω_19.1, D7.4 (BA)
unnamed: 220Ω_20.1, D7.5 (GA)
unnamed: 220Ω_21.1, D7.6 (RA)
unnamed: 220Ω_22.1, D8.4 (BA)
unnamed: 220Ω_23.1, D8.5 (GA)
unnamed: 220Ω_24.1, D8.6 (RA)
unnamed: 220Ω_25.1, D9.4 (BA)
unnamed: 220Ω_26.1, D9.5 (GA)
unnamed: 220Ω_27.1, D9.6 (RA)
unnamed: 220Ω_28.1, D10.4 (BA)
unnamed: 220Ω_29.1, D10.5 (GA)
unnamed: 220Ω_30.1, D10.6 (RA)
unnamed: 220Ω_31.1, D11.4 (BA)
unnamed: 220Ω_32.1, D11.5 (GA)
unnamed: 220Ω_33.1, D11.6 (RA)
unnamed: 220Ω_34.1, D12.4 (BA)
unnamed: 220Ω_35.1, D12.5 (GA)
unnamed: 220Ω_36.1, D12.6 (RA)
unnamed: D14.1 (K), PR1.1, PR2.1, PR3.1, PR4.1, PR5.1, PR6.1, PR7.1, PR8.1, Q1.1 (C), Q2.1 (C), Q3.1 (C)
unnamed: Q1.2 (B), R1.1
unnamed: 220Ω_3.2, 220Ω_6.2, 220Ω_9.2, 220Ω_12.2, 220Ω_15.2, 220Ω_18.2, 220Ω_21.2, 220Ω_24.2, 220Ω_27.2, 220Ω_30.2, 220Ω_33.2, 220Ω_36.2, Q1.3 (E)
unnamed: Q2.2 (B), R2.1
unnamed: 220Ω_2.2, 220Ω_5.2, 220Ω_8.2, 220Ω_11.2, 220Ω_14.2, 220Ω_17.2, 220Ω_20.2, 220Ω_23.2, 220Ω_26.2, 220Ω_29.2, 220Ω_32.2, 220Ω_35.2, Q2.3 (E)
unnamed: Q3.2 (B), R3.1
unnamed: 220Ω_1.2, 220Ω_4.2, 220Ω_7.2, 220Ω_10.2, 220Ω_13.2, 220Ω_16.2, 220Ω_19.2, 220Ω_22.2, 220Ω_25.2, 220Ω_28.2, 220Ω_31.2, 220Ω_34.2, Q3.3 (E)
ROOD: J2.5, R3.2
pr1: 10KΩ_1.1, J1.3, PR1.2
pr2: 10KΩ_2.1, J1.2, PR2.2
pr3: 10KΩ_3.1, J1.1, PR3.2
pr4: 10KΩ_4.1, J2.10, PR4.2
pr5: 10KΩ_5.1, J2.9, PR5.2
pr6: 10KΩ_6.1, J2.8, PR6.2
pr7: 10KΩ_7.1, J2.7, PR7.2
pr8: 10KΩ_8.1, J2.6, PR8.2

Board: 2 copper layers, 77 parts (0 on the bottom side), 57 nets, no tracks yet.

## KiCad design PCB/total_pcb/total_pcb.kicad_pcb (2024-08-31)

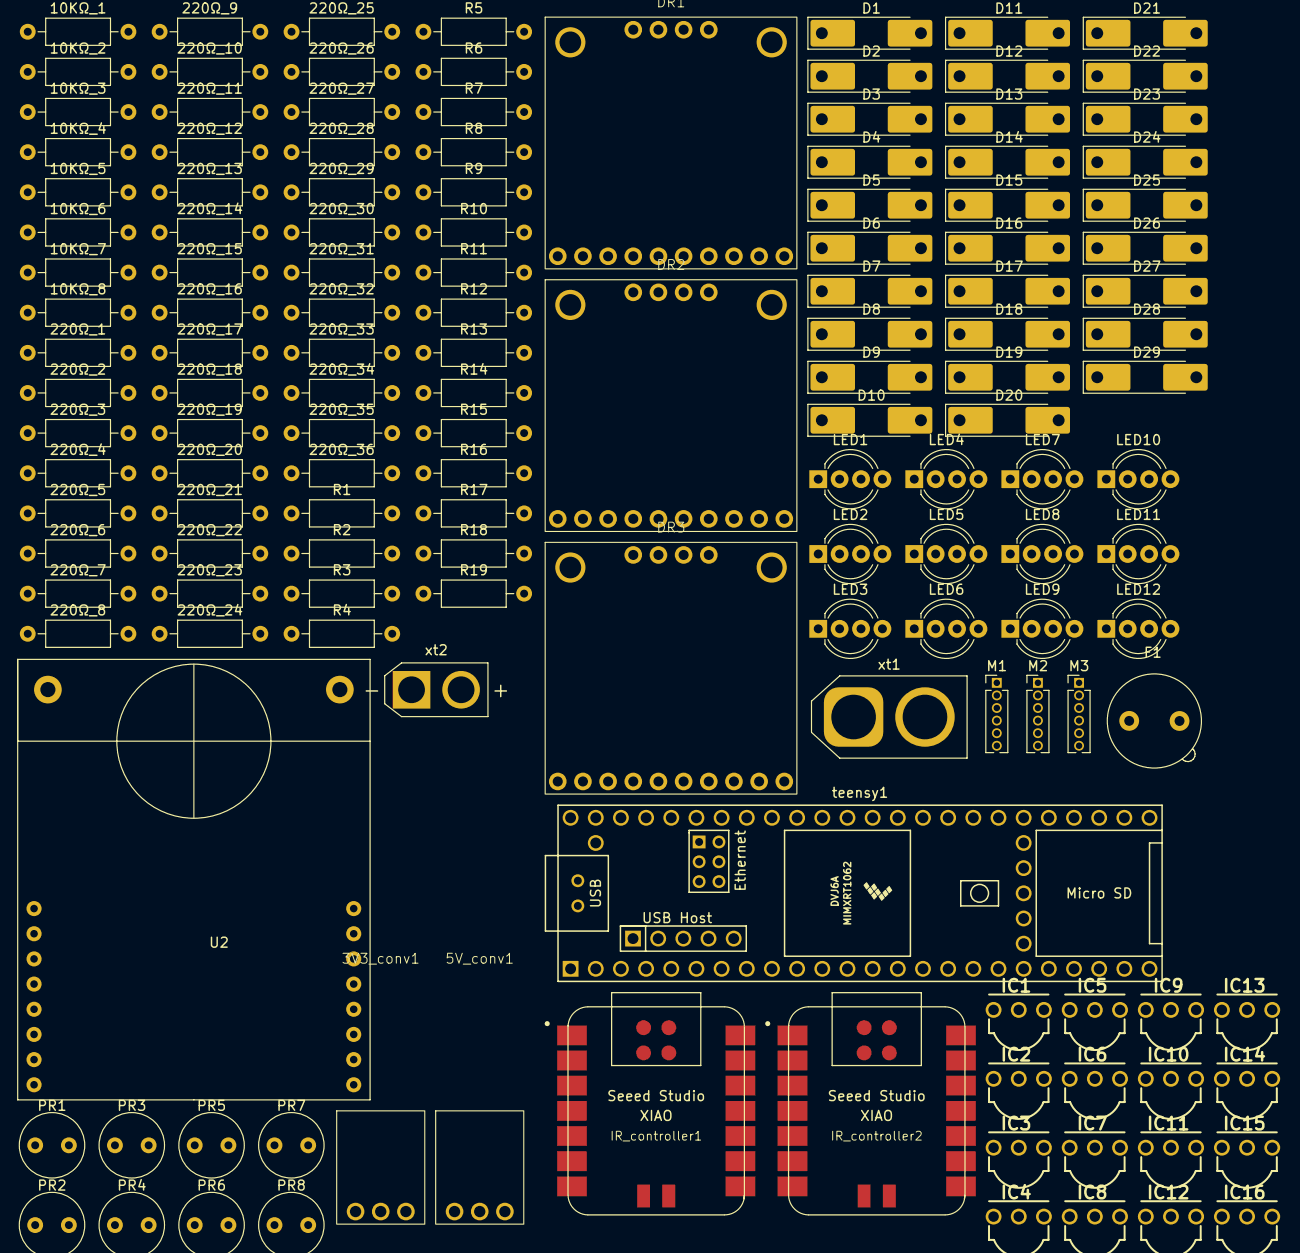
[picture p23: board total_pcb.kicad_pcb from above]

Board: 2 copper layers, 143 parts (0 on the bottom side), 140 nets, no tracks yet.

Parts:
3V3_conv1, 5V_conv1: pololu-U1V10F5
10KΩ_1, 10KΩ_2, 10KΩ_3, 10KΩ_4, 10KΩ_5, 10KΩ_6, 10KΩ_7, 10KΩ_8, 220Ω_1, 220Ω_2, 220Ω_3, 220Ω_4, 220Ω_5, 220Ω_6, 220Ω_7, 220Ω_8, 220Ω_9, 220Ω_10, 220Ω_11, 220Ω_12, 220Ω_13, 220Ω_14, 220Ω_15, 220Ω_16, 220Ω_17, 220Ω_18, 220Ω_19, 220Ω_20, 220Ω_21, 220Ω_22, 220Ω_23, 220Ω_24, 220Ω_25, 220Ω_26, 220Ω_27, 220Ω_28, 220Ω_29, 220Ω_30, 220Ω_31, 220Ω_32, 220Ω_33, 220Ω_34, 220Ω_35, 220Ω_36: R_US; R_Axial_DIN0207_L6.3mm_D2.5mm_P10.16mm_Horizontal
D1, D2, D3, D4, D5, D6, D7, D8, D9, D10, D11, D12, D13, D14, D15, D16, D17, D18, D19, D20, D21, D22, D23, D24, D25, D26, D27, D28, D29: D; D_MELF-RM10_Universal_Handsoldering
DR1, DR2, DR3: TB9051FTG
F1: Fuse; Fuseholder_TR5_Littelfuse_No560_No460
IC1, IC2, IC3, IC4, IC5, IC6, IC7, IC8, IC9, IC10, IC11, IC12, IC13, IC14, IC15, IC16: TSSP4038
IR_controller1, IR_controller2: Seeed Studio XIAO SAMD21; XIAO-SAMD21-RP2040-14P-2.54-21X17.8MM (Seeeduino XIAO)
LED1, LED2, LED3, LED4, LED5, LED6, LED7, LED8, LED9, LED10, LED11, LED12: LED_KRGB; LED_D5.0mm-4_RGB_Wide_Pins
M1, M2, M3: PinHeader_1x06_P1.27mm_Vertical
PR1, PR2, PR3, PR4, PR5, PR6, PR7, PR8: A1050; R_LDR_D6.4mm_P3.4mm_Vertical
R1, R2, R3, R4, R5, R6, R7, R8, R9, R10, R11, R12, R13, R14, R15, R16, R17, R18, R19: R_US; R_Axial_DIN0207_L6.3mm_D2.5mm_P10.16mm_Horizontal
U2: openMV_M7_R2; openmv_m7_r2
teensy1: Teensy4.1; Teensy41
xt1: Battery; AMASS_XT60-F_1x02_P7.20mm_Vertical
xt2: Battery; AMASS_XT30U-M_1x02_P5.0mm_Vertical

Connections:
3v3: D7.2 (A), D21.1 (K)
5V: D16.2 (A), D23.1 (K)
5v: D8.2 (A), D20.1 (K)
BLAUW: R17.2, teensy1.38 (16_A2_RX4_SCL1)
GND: D17.1 (K), D24.2 (A), D26.2 (A)
GROEN: R18.2, teensy1.25 (33_MCLK2)
unnamed: 3V3_conv1.3 (VIN), 5V_conv1.3 (VIN), D12.1 (K)
unnamed: D1.2 (A), D4.2 (A), D7.1 (K)
unnamed: D1.1 (K), IR_controller1.12 (3V3)
unnamed: D2.2 (A), IR_controller1.13 (GND)
unnamed: D2.1 (K), D3.1 (K), D5.1 (K), D9.2 (A), D29.1 (K), U2.screw
unnamed: D3.2 (A), IR_controller2.13 (GND)
unnamed: D4.1 (K), IR_controller2.12 (3V3)
unnamed: D5.2 (A), U2.17 (gnd)
unnamed: D6.1 (K), U2.16 (vin)
unnamed: D10.2 (A), xt1.2 (-), xt2.2 (-)
unnamed: D10.1 (K), F1.2
unnamed: D11.2 (A), D13.1 (K), D26.1 (K), D27.2 (A), DR1.0 (screw), DR1.6 (GND), DR2.0 (screw), DR2.6 (GND), DR3.0 (screw), DR3.6 (GND)
unnamed: D11.1 (K), xt1.1 (+), xt2.1 (+)
unnamed: D12.2 (A), D25.2 (A), DR1.1 (VIN), DR2.1 (VIN), DR3.1 (VIN), F1.1
unnamed: D13.2 (A), D19.1 (K), D22.1 (K), D24.1 (K)
unnamed: D14.1 (K), D18.2 (A), D20.2 (A), D23.2 (A), DR1.7 (VCC), DR2.7 (VCC), DR3.7 (VCC), M1.4 (Vcc), M2.4 (Vcc), M3.4 (Vcc)
unnamed: D15.1 (K), D21.2 (A)
unnamed: D16.1 (K), PR1.1, PR2.1, PR3.1, PR4.1, PR5.1, PR6.1, PR7.1, PR8.1
unnamed: 10KΩ_1.2, 10KΩ_2.2, 10KΩ_3.2, 10KΩ_4.2, 10KΩ_5.2, 10KΩ_6.2, 10KΩ_7.2, 10KΩ_8.2, D17.2 (A), LED1.1 (K), LED2.1 (K), LED3.1 (K), LED4.1 (K), LED5.1 (K), LED6.1 (K), LED7.1 (K), LED8.1 (K), LED9.1 (K), LED10.1 (K), LED11.1 (K), LED12.1 (K)
unnamed: D18.1 (K), teensy1.48 (VIN)
unnamed: D19.2 (A), teensy1.47 (GND)
unnamed: D27.1 (K), DR1.2 (GND), DR2.2 (GND), DR3.2 (GND), M1.3 (GND), M2.3 (GND), M3.3 (GND)
unnamed: D6.2 (A), D8.1 (K), D28.2 (A)
unnamed: D28.1 (K), R1.2, R2.2, R3.2, R4.2, R5.2, R6.2, R7.2, R8.2, R9.2, R10.2, R11.2, R12.2, R13.2, R14.2, R15.2, R16.2
unnamed: D29.2 (A), IC1.2 (GND), IC2.2 (GND), IC3.2 (GND), IC4.2 (GND), IC5.2 (GND), IC6.2 (GND), IC7.2 (GND), IC8.2 (GND), IC9.2 (GND), IC10.2 (GND), IC11.2 (GND), IC12.2 (GND), IC13.2 (GND), IC14.2 (GND), IC15.2 (GND), IC16.2 (GND)
unnamed: DR1.9 (EN), teensy1.19 (27_A13_SCK1)
unnamed: DR1.10 (ENB), teensy1.18 (26_A12_MOSI1)
unnamed: DR1.4 (OUT1), M1.1 (MotorPW)
unnamed: DR1.3 (OUT2), M1.2 (MotorPW)
unnamed: DR1.12 (PWM1), teensy1.16 (24_A10_TX6_SCL2)
unnamed: DR1.11 (PWM2), teensy1.17 (25_A11_RX6_SDA2)
unnamed: DR2.9 (EN), teensy1.14 (12_MISO_MQSL)
unnamed: DR2.10 (ENB), teensy1.13 (11_MOSI_CTX1)
unnamed: DR2.4 (OUT1), M2.1 (MotorPW)
unnamed: DR2.3 (OUT2), M2.2 (MotorPW)
unnamed: DR2.12 (PWM1), teensy1.11 (9_OUT1C)
unnamed: DR2.11 (PWM2), teensy1.12 (10_CS_MQSR)
unnamed: DR3.9 (EN), teensy1.8 (6_OUT1D)
unnamed: DR3.10 (ENB), teensy1.7 (5_IN2)
unnamed: DR3.4 (OUT1), M3.1 (MotorPW)
unnamed: DR3.3 (OUT2), M3.2 (MotorPW)
unnamed: DR3.12 (PWM1), teensy1.5 (3_LRCLK2)
unnamed: DR3.11 (PWM2), teensy1.6 (4_BCLK2)
unnamed: IC1.1 (OUT), IR_controller1.1 (PA02_A0_D0)
unnamed: IC1.3 (VS), R1.1
unnamed: IC2.1 (OUT), IR_controller1.2 (PA4_A1_D1)
unnamed: IC2.3 (VS), R2.1
unnamed: IC3.3 (VS), R3.1
unnamed: IC4.1 (OUT), IR_controller1.3 (PA10_A2_D2)
unnamed: IC4.3 (VS), R4.1
unnamed: IC5.1 (OUT), IR_controller1.4 (PA11_A3_D3)
unnamed: IC5.3 (VS), R5.1
unnamed: IC6.1 (OUT), IR_controller1.5 (PA8_A4_D4_SDA)
unnamed: IC6.3 (VS), R6.1
unnamed: IC7.1 (OUT), IR_controller1.6 (PA9_A5_D5_SCL)
unnamed: IC7.3 (VS), R7.1
unnamed: IC8.1 (OUT), IR_controller1.9 (PA7_A8_D8_SCK)
unnamed: IC8.3 (VS), R8.1
unnamed: IC9.1 (OUT), IR_controller2.1 (PA02_A0_D0)
unnamed: IC9.3 (VS), R9.1
unnamed: IC10.1 (OUT), IR_controller2.2 (PA4_A1_D1)
unnamed: IC10.3 (VS), R10.1
unnamed: IC11.3 (VS), R11.1
unnamed: IC12.1 (OUT), IR_controller2.3 (PA10_A2_D2)
unnamed: IC12.3 (VS), R12.1
unnamed: IC13.1 (OUT), IR_controller2.4 (PA11_A3_D3)
unnamed: IC13.3 (VS), R13.1
unnamed: IC14.1 (OUT), IR_controller2.5 (PA8_A4_D4_SDA)
unnamed: IC14.3 (VS), R14.1
unnamed: IC15.1 (OUT), IR_controller2.6 (PA9_A5_D5_SCL)
unnamed: IC15.3 (VS), R15.1
unnamed: IC16.1 (OUT), IR_controller2.9 (PA7_A8_D8_SCK)
unnamed: IC16.3 (VS), R16.1
unnamed: 220Ω_3.1, LED1.4 (BA)
unnamed: 220Ω_2.1, LED1.3 (GA)
unnamed: 220Ω_1.1, LED1.2 (RA)
unnamed: 220Ω_6.1, LED2.4 (BA)
unnamed: 220Ω_5.1, LED2.3 (GA)
unnamed: 220Ω_4.1, LED2.2 (RA)
unnamed: 220Ω_9.1, LED3.4 (BA)
unnamed: 220Ω_8.1, LED3.3 (GA)
unnamed: 220Ω_7.1, LED3.2 (RA)
unnamed: 220Ω_12.1, LED4.4 (BA)
unnamed: 220Ω_11.1, LED4.3 (GA)
unnamed: 220Ω_10.1, LED4.2 (RA)
unnamed: 220Ω_15.1, LED5.4 (BA)
unnamed: 220Ω_14.1, LED5.3 (GA)
unnamed: 220Ω_13.1, LED5.2 (RA)
unnamed: 220Ω_18.1, LED6.4 (BA)
unnamed: 220Ω_17.1, LED6.3 (GA)
unnamed: 220Ω_16.1, LED6.2 (RA)
unnamed: 220Ω_21.1, LED7.4 (BA)
unnamed: 220Ω_20.1, LED7.3 (GA)
unnamed: 220Ω_19.1, LED7.2 (RA)
unnamed: 220Ω_24.1, LED8.4 (BA)
unnamed: 220Ω_23.1, LED8.3 (GA)
unnamed: 220Ω_22.1, LED8.2 (RA)
unnamed: 220Ω_27.1, LED9.4 (BA)
unnamed: 220Ω_26.1, LED9.3 (GA)
unnamed: 220Ω_25.1, LED9.2 (RA)
unnamed: 220Ω_30.1, LED10.4 (BA)
unnamed: 220Ω_29.1, LED10.3 (GA)
unnamed: 220Ω_28.1, LED10.2 (RA)
unnamed: 220Ω_33.1, LED11.4 (BA)
unnamed: 220Ω_32.1, LED11.3 (GA)
unnamed: 220Ω_31.1, LED11.2 (RA)
unnamed: 220Ω_36.1, LED12.4 (BA)
unnamed: 220Ω_35.1, LED12.3 (GA)
unnamed: 220Ω_34.1, LED12.2 (RA)
unnamed: M1.5 (A_out), teensy1.20 (28_RX7)
unnamed: M1.6 (B_out), teensy1.45 (23_A9_CRX1_MCLK1)
unnamed: M2.5 (A_out), teensy1.22 (30_CRX3)
unnamed: M2.6 (B_out), teensy1.21 (29_TX7)
unnamed: M3.5 (A_out), teensy1.24 (32_OUT1B)
unnamed: M3.6 (B_out), teensy1.23 (31_CTX3)
unnamed: 220Ω_3.2, 220Ω_6.2, 220Ω_9.2, 220Ω_12.2, 220Ω_15.2, 220Ω_18.2, 220Ω_21.2, 220Ω_24.2, 220Ω_27.2, 220Ω_30.2, 220Ω_33.2, 220Ω_36.2
unnamed: 220Ω_2.2, 220Ω_5.2, 220Ω_8.2, 220Ω_11.2, 220Ω_14.2, 220Ω_17.2, 220Ω_20.2, 220Ω_23.2, 220Ω_26.2, 220Ω_29.2, 220Ω_32.2, 220Ω_35.2
unnamed: 220Ω_1.2, 220Ω_4.2, 220Ω_7.2, 220Ω_10.2, 220Ω_13.2, 220Ω_16.2, 220Ω_19.2, 220Ω_22.2, 220Ω_25.2, 220Ω_28.2, 220Ω_31.2, 220Ω_34.2
ROOD: R19.2, teensy1.26 (34_RX8)
gnd: D9.1 (K), D22.2 (A)
pr1: 10KΩ_1.1, PR1.2, teensy1.35 (13_SCK_LED)
pr2: 10KΩ_2.1, PR2.2, teensy1.33 (41_A17)
pr3: 10KΩ_3.1, PR3.2, teensy1.32 (40_A16)
pr4: 10KΩ_4.1, PR4.2, teensy1.31 (39_MISO1_OUT1A)
pr5: 10KΩ_5.1, PR5.2, teensy1.30 (38_CS1_IN1)
pr6: 10KΩ_6.1, PR6.2, teensy1.29 (37_CS)
pr7: 10KΩ_7.1, PR7.2, teensy1.28 (36_CS)
pr8: 10KΩ_8.1, PR8.2, teensy1.27 (35_TX8)
rx1: U2.3 (p1/TX/miso), teensy1.2 (0_RX1_CRX2_CS1)
rx2: IR_controller1.7 (PB08_A6_D6_TX), teensy1.9 (7_RX2_OUT1A)
rx3: IR_controller2.7 (PB08_A6_D6_TX), teensy1.37 (15_A1_RX3_SPDIF_IN)
tx1: U2.2 (p0/RX/mosi), teensy1.3 (1_TX1_CTX2_MISO1)
tx2: IR_controller1.8 (PB09_A7_D7_RX), teensy1.10 (8_TX2_IN1)
tx3: IR_controller2.8 (PB09_A7_D7_RX), teensy1.36 (14_A0_TX3_SPDIF_OUT)

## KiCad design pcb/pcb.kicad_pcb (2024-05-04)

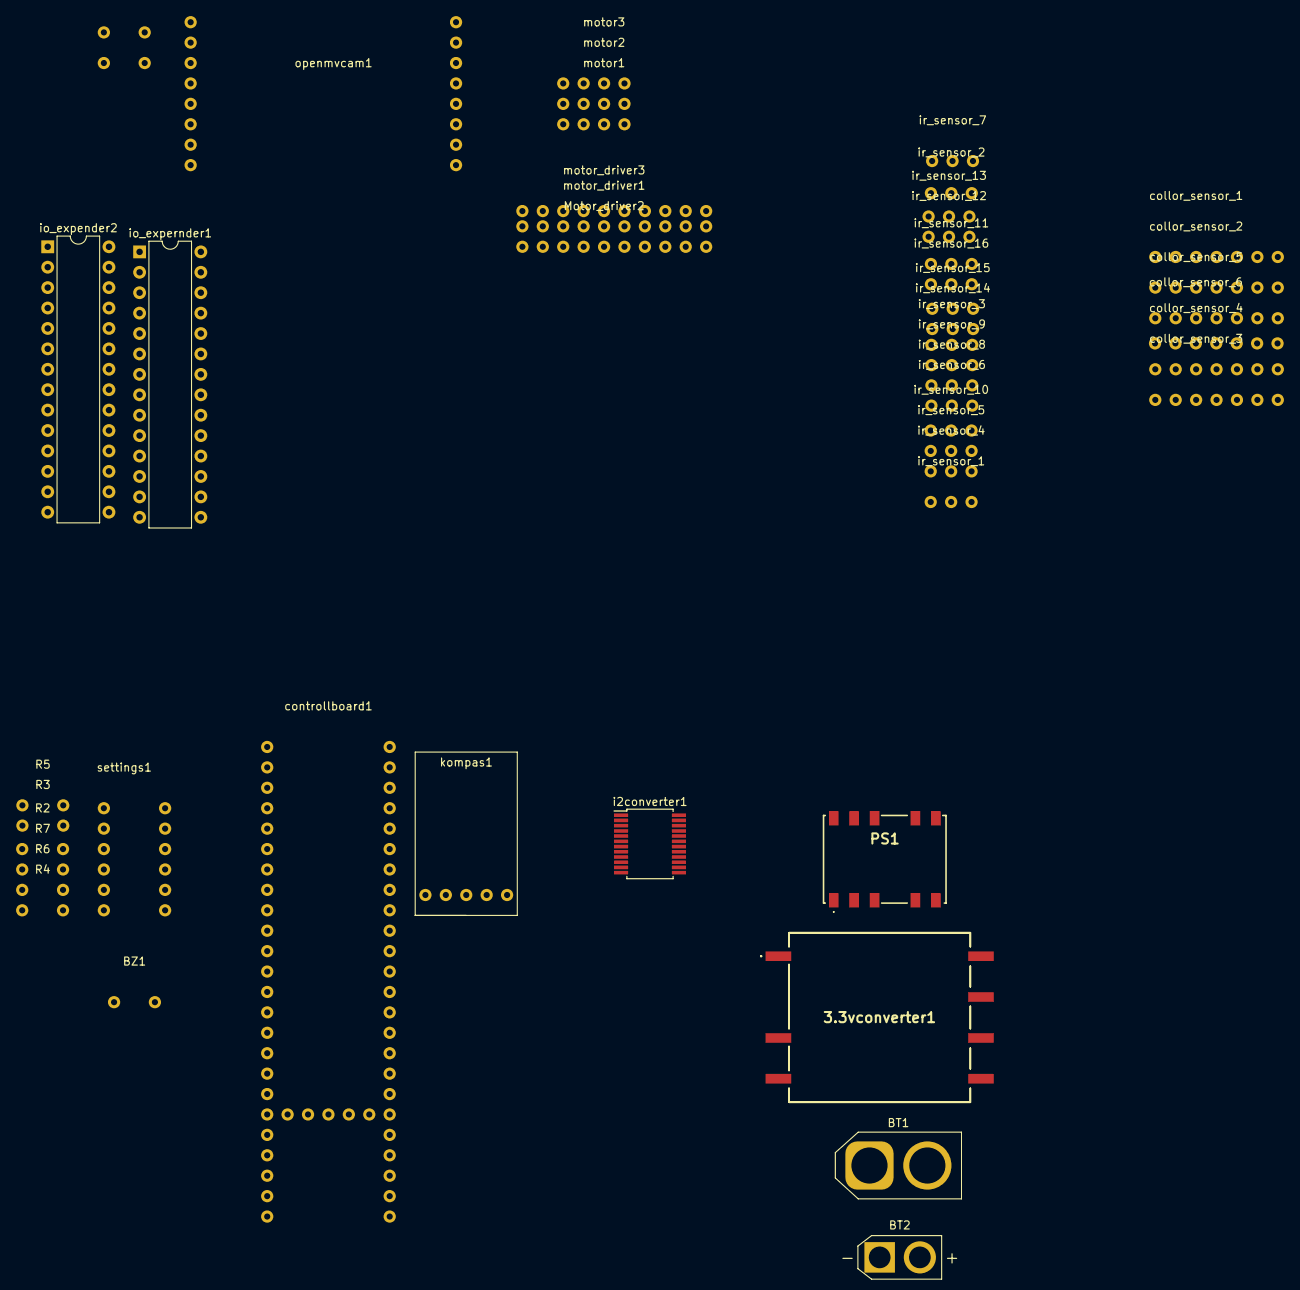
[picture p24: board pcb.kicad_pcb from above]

Board: 2 copper layers, 48 parts (0 on the bottom side), 67 nets, no tracks yet.

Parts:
3.3vconverter1: CC6-1203SR-E; CC60512SRE
BT1: Battery; AMASS_XT60-F_1x02_P7.20mm_Vertical
BT2: Battery; AMASS_XT30U-F_1x02_P5.0mm_Vertical
BZ1: Buzzer; buzer
Motor_driver2: TB9051FTG
PS1: SFTN01M-05N; SFTN01M05N
R1, R2, R3, R4, R5, R6, R7: R; resistor
collor_sensor_1, collor_sensor_2, collor_sensor_3, collor_sensor_4, collor_sensor_5, collor_sensor_6: tcs3472_color_sensor; tcs3472
controllboard1: Teensy4.1; teensy4.1
i2converter1: PCA9548ADB; SSOP-24_5.3x8.2mm_P0.65mm
io_expender2: MCP23017_SP; DIP-28_W7.62mm
io_expernder1: MCP23017_SP; DIP-28_W7.62mm
ir_sensor_1, ir_sensor_2, ir_sensor_3, ir_sensor_4, ir_sensor_5, ir_sensor_6, ir_sensor_7, ir_sensor_8, ir_sensor_9, ir_sensor_10, ir_sensor_11, ir_sensor_12, ir_sensor_13, ir_sensor_14, ir_sensor_15, ir_sensor_16: tssp4038
kompas1: miniIMU-9_v6
motor1, motor2, motor3: pololu_motor
motor_driver1, motor_driver3: TB9051FTG
openmvcam1: openMV_M7_R2; openmv_m7_r2
set_goal_color1: SW_DIP_x01; dipswitch1
settings1: SW_DIP_x06; dipswitch6

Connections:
12v: 3.3vconverter1.1, BT1.2, BT2.2, PS1.2
unnamed: 3.3vconverter1.5, R1.2, collor_sensor_1.3, collor_sensor_2.3, collor_sensor_3.3, collor_sensor_4.3, collor_sensor_5.3, collor_sensor_6.3, i2converter1.12, io_expender2.10, io_expernder1.10, ir_sensor_1.2, ir_sensor_2.2, ir_sensor_3.2, ir_sensor_4.2, ir_sensor_5.2, ir_sensor_6.2, ir_sensor_7.2, ir_sensor_8.2, ir_sensor_9.2, ir_sensor_10.2, ir_sensor_11.2, ir_sensor_12.2, ir_sensor_13.2, ir_sensor_14.2, ir_sensor_15.2, ir_sensor_16.2
unnamed: 3.3vconverter1.7, collor_sensor_1.2, collor_sensor_2.2, collor_sensor_3.2, collor_sensor_4.2, collor_sensor_5.2, collor_sensor_6.2, i2converter1.24, io_expender2.9, io_expernder1.9, ir_sensor_1.1, ir_sensor_2.1, ir_sensor_3.1, ir_sensor_4.1, ir_sensor_5.1, ir_sensor_6.1, ir_sensor_7.1, ir_sensor_8.1, ir_sensor_9.1, ir_sensor_10.1, ir_sensor_11.1, ir_sensor_12.1, ir_sensor_13.1, ir_sensor_14.1, ir_sensor_15.1, ir_sensor_16.1, set_goal_color1.1
unnamed: BZ1.1, controllboard1.10
unnamed: BZ1.2, Motor_driver2.6, PS1.5, R2.2, R3.2, R4.2, R5.2, R6.2, R7.2, controllboard1.47, kompas1.2, motor1.4, motor2.4, motor3.4, motor_driver1.6, motor_driver3.6
unnamed: Motor_driver2.7, PS1.8, controllboard1.48, kompas1.3, motor1.1, motor2.1, motor3.1, motor_driver1.7, motor_driver3.7
unnamed: Motor_driver2.9, io_expender2.5
unnamed: Motor_driver2.10, io_expender2.4
unnamed: Motor_driver2.11, io_expender2.3
unnamed: Motor_driver2.12, io_expender2.2
unnamed: R1.1, set_goal_color1.2
unnamed: R2.1, controllboard1.4, settings1.7
unnamed: R3.1, controllboard1.5, settings1.8
unnamed: R4.1, controllboard1.6, settings1.9
unnamed: R5.1, controllboard1.7, settings1.10
unnamed: R6.1, controllboard1.8, settings1.11
unnamed: R7.1, controllboard1.9, settings1.12
unnamed: collor_sensor_1.0, i2converter1.15
unnamed: collor_sensor_1.1, i2converter1.16
unnamed: collor_sensor_2.0, i2converter1.13
unnamed: collor_sensor_2.1, i2converter1.14
unnamed: collor_sensor_3.0, i2converter1.10
unnamed: collor_sensor_3.1, i2converter1.11
unnamed: collor_sensor_4.0, i2converter1.9
unnamed: collor_sensor_4.1, i2converter1.8
unnamed: collor_sensor_5.0, i2converter1.6
unnamed: collor_sensor_5.1, i2converter1.7
unnamed: collor_sensor_6.0, i2converter1.4
unnamed: collor_sensor_6.1, i2converter1.5
unnamed: controllboard1.40, i2converter1.23, kompas1.1
unnamed: controllboard1.41, i2converter1.22, kompas1.0
unnamed: controllboard1.44, motor_driver3.11
unnamed: controllboard1.45, motor_driver3.12
unnamed: controllboard1.46, settings1.1, settings1.2, settings1.3, settings1.4, settings1.5, settings1.6
unnamed: i2converter1.17, io_expernder1.13
unnamed: i2converter1.18, io_expernder1.12
unnamed: i2converter1.19, io_expender2.13
unnamed: i2converter1.20, io_expender2.12
unnamed: io_expender2.1, motor_driver3.9
unnamed: io_expender2.6, motor_driver1.12
unnamed: io_expender2.7, motor_driver1.11
unnamed: io_expender2.8, motor_driver1.10
unnamed: io_expender2.21, motor_driver1.9
unnamed: io_expender2.22, ir_sensor_15.3
unnamed: io_expender2.23, ir_sensor_14.3
unnamed: io_expender2.24, motor_driver3.10
unnamed: io_expender2.25, motor2.2
unnamed: io_expender2.26, motor2.3
unnamed: io_expender2.27, motor3.2
unnamed: io_expender2.28, motor3.3
unnamed: io_expernder1.1, ir_sensor_1.3
unnamed: io_expernder1.2, ir_sensor_2.3
unnamed: io_expernder1.3, ir_sensor_4.3
unnamed: io_expernder1.4, ir_sensor_5.3
unnamed: io_expernder1.5, ir_sensor_6.3
unnamed: io_expernder1.6, ir_sensor_7.3
unnamed: io_expernder1.7, ir_sensor_8.3
unnamed: io_expernder1.8, ir_sensor_9.3
unnamed: io_expernder1.21, ir_sensor_10.3
unnamed: io_expernder1.22, ir_sensor_11.3
unnamed: io_expernder1.23, ir_sensor_12.3
unnamed: io_expernder1.24, ir_sensor_13.3
unnamed: io_expernder1.25, ir_sensor_16.3
unnamed: io_expernder1.26, ir_sensor_3.3
unnamed: io_expernder1.27, motor1.2
unnamed: io_expernder1.28, motor1.3
gnd: 3.3vconverter1.3, BT1.1, BT2.1, PS1.1

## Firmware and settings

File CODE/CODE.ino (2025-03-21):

#include <TimerThree.h>
#include <Arduino.h>

int speed = 1000; // speed 0-1

volatile int PWMval1 = 0;   // PWM value 0-100
volatile int PWMval2 = 0;   // PWM value 0-100
volatile int PWMval3 = 0;   // PWM value 0-100

int incomingbyte1 = 0;  //the byte that it is reciefing
bool iswriting1 = false;  //true if writing else fals
String tlocdat1 = "";  //temporary location data
String locdat1 = "";   //location data
int nir1 = "-99"; // which ir sensor it is
int pir1 = "-99"; // amount of pulses it had

int incomingbyte2 = 0;  //same but for seeed xiao N 2
bool iswriting2 = false;
String tlocdat2 = ""; 
String locdat2 = ""; 
int nir2 = "-99";
int pir2 = "-99";

float degwhere = -99.0; // where the ball is in degrees

int led = 13;

int m1enA = 6;
int m1enB = 5;
int m1pwm1 = 4;
int m1pwm2 = 3;
int m1encoA = 32;
int m1encoB = 31;

int m2enA = 12;
int m2enB = 11;
int m2pwm1 = 9;
int m2pwm2 = 10;
int m2encoA = 30;
int m2encoB = 29;

int m3enA = 27;
int m3enB = 26;
int m3pwm1 = 24;
int m3pwm2 = 25;
int m3encoA = 28;
int m3encoB = 23;

int softpwr = 2;

int pr1 = 13;
int pr2 = 41;
int pr3 = 40;
int pr4 = 39;
int pr5 = 38;
int pr6 = 37;
int pr7 = 36;
int pr8 = 35;

int dpr1 = "LOW";
int dpr2 = "LOW";
int dpr3 = "LOW";
int dpr4 = "LOW";
int dpr5 = "LOW";
int dpr6 = "LOW";
int dpr7 = "LOW";
int dpr8 = "LOW";

double sp1 = 0.00;
double sp2 = 0.00;
double sp3 = 0.00;

void setup() {
  pinMode(m1enA, OUTPUT);
  pinMode(m1enB, OUTPUT);
  pinMode(m1pwm1, OUTPUT);
  pinMode(m1pwm2, OUTPUT);
  
  pinMode(m2enA, OUTPUT);
  pinMode(m2enB, OUTPUT);
  pinMode(m2pwm1, OUTPUT);
  pinMode(m2pwm2, OUTPUT);
  
  pinMode(m3enA, OUTPUT);
  pinMode(m3enB, OUTPUT);
  pinMode(m3pwm1, OUTPUT);
  pinMode(m3pwm2, OUTPUT);

  pinMode(softpwr, INPUT_PULLUP);

  pinMode(pr1, INPUT);
  pinMode(pr2, INPUT);
  pinMode(pr3, INPUT);
  pinMode(pr4, INPUT);
  pinMode(pr5, INPUT);
  pinMode(pr6, INPUT);
  pinMode(pr7, INPUT);
  pinMode(pr8, INPUT);

  Serial.begin(9600);
  Serial3.begin(9600);
  Serial2.begin(9600);

  Timer3.initialize(800); // 800 microseconds / 1.25kHz
  Timer3.attachInterrupt(updatePWM); 
}

void updatePWM() {
  static int counter = 0;

  if (counter < PWMval1) {
    digitalWrite(m1enA, HIGH);
  } else {
    digitalWrite(m1enA, LOW);
  }
  
  if (counter < PWMval2) {
    digitalWrite(m2enA, HIGH);
  } else {
    digitalWrite(m2enA, LOW);
  }
  
  if (counter < PWMval3) {
    digitalWrite(m3enA, HIGH);
  } else {
    digitalWrite(m3enA, LOW);
  }

  counter++;
  if (counter >= 100) {
    counter = 0;
  }
}

void mcpsoftpwm1(int value1) {
  if (value1 < 0) value1 = 0;
  if (value1 > 100) value1 = 100;

  Serial.print("softPWM pin: enA, value: ");
  Serial.println(value1); 
  PWMval1 = value1; 
}
void mcpsoftpwm2(int value2) {
  if (value2 < 0) value2 = 0;
  if (value2 > 100) value2 = 100;

  Serial.print("softPWM pin: enA, value: ");
  Serial.println(value2); 
  PWMval2 = value2; 
}void mcpsoftpwm3(int value3) {
  if (value3 < 0) value3 = 0;
  if (value3 > 100) value3 = 100;

  Serial.print("softPWM pin: enA, value: ");
  Serial.println(value3); 
  PWMval3 = value3; 
}

void move1(int sped1) {
  sp1 = abs(sped1)*0.1;
  mcpsoftpwm1(sp1);
  digitalWrite(m1enB, LOW);
  if (sped1 < 0) {
    Serial.print("back ");
    digitalWrite(m1pwm1, LOW);
    digitalWrite(m1pwm2, HIGH);
  } else {
    Serial.print("forward ");
    digitalWrite(m1pwm1, HIGH);
    digitalWrite(m1pwm2, LOW);
  } 
  Serial.println(sp1);
}

void move2(int sped2) {
  sp2 = abs(sped2)*0.1;
  mcpsoftpwm2(sp2);
  digitalWrite(m2enB, LOW);
  if (sped2 < 0) {
    Serial.print("back ");
    digitalWrite(m2pwm1, LOW);
    digitalWrite(m2pwm2, HIGH);
  } else {
    Serial.print("forward ");
    digitalWrite(m2pwm1, HIGH);
    digitalWrite(m2pwm2, LOW);
  } 
  Serial.println(sp2);
}

void move3(int sped3) {
  sp3 = abs(sped3)*0.1;
  mcpsoftpwm3(sp3);
  digitalWrite(m3enB, LOW);
  if (sped3 < 0) {
    Serial.print("back ");
    digitalWrite(m3pwm1, LOW);
    digitalWrite(m3pwm2, HIGH);
  } else {
    Serial.print("forward ");
    digitalWrite(m3pwm1, HIGH);
    digitalWrite(m3pwm2, LOW);
  } 
  Serial.println(sp3);
}


void drive(int speeeed, int direction){
 //
 // Direction............|.Motor 1.|.Motor 2.|.Motor 3.
 // 0deg(forward)........|....0....|....-....|....+....
 // 60deg................|....+....|....-....|....0....    
 // 120deg...............|....+....|....0....|....-....
 // 180 deg (backward)...|....0....|....+....|....-.... 
 // 240 deg..............|....-....|....+....|....0....
 // 300 deg..............|....-....|....0....|....+....
 //
 if(direction>330 || direction<=30){
    //0 deg
    //Serial.println("drive 0 deg"); 
    move1(0);
    move2(-speeeed);
    move3(speeeed);
  }else if (direction>30 && direction <= 90){
    //60 deg
    //Serial.println("drive 60deg");
    move1(speeeed);
    move2(-speeeed);
    move3(0);
  }else if (direction>90 && direction <= 150){
    //120 deg
    //Serial.println("drive 120 deg");
    move1(speeeed);
    move2(0);
    move3(-speeeed);
  }else if (direction > 150 && direction <= 210) {
    //180 degrees
    //Serial.println("drive  180 deg");
    move1(0);
    move2(speeeed);
    move3(-speeeed);
  }else if (direction > 210 && direction <= 270) {
    //240 degrees
    //Serial.println("drive 240 deg");
    move1(-speeeed);
    move2(speeeed);
    move3(0);
  }else if (direction > 270 && direction <= 330) {
    //300 degrees
    //Serial.println("drive 300 deg");
    move1(-speeeed);
    move2(0);
    move3(speeeed);
  }else{
    Serial.println("how?");  
  }
}

void loop() {
  int sprst = digitalRead(softpwr);  //softpower status
  if(sprst == LOW){
    dpr1 = digitalRead(pr1);
    dpr2 = digitalRead(pr2); 
    dpr3 = digitalRead(pr3); 
    dpr4 = digitalRead(pr4); 
    dpr5 = digitalRead(pr5); 
    dpr6 = digitalRead(pr6); 
    dpr7 = digitalRead(pr7); 
    dpr8 = digitalRead(pr8); 
  
    if(dpr1 == HIGH){
      //go back to ?deg
    }else if (dpr2 == HIGH){
      //go back to ?deg
    }else if (dpr3 == HIGH){
      //go back to ?deg
    }else if (dpr4 == HIGH){
      //go back to ?deg
    }else if (dpr5 == HIGH){
      //go back to ?deg
    }else if (dpr6 == HIGH){
      //go back to ?deg
    }else if (dpr7 == HIGH){
      //go back to ?deg
    }else if (dpr8 == HIGH){
      //go back to ?deg
    }else{
      if (Serial3.available() > 0) {
        incomingbyte1 = Serial3.read();
        //Serial.print(char(incomingbyte1));
        if (incomingbyte1 == 's'){
          iswriting1 = true;
          tlocdat1 = "";
        }else if(incomingbyte1 == 'e'){
          iswriting1 = false;
          locdat1 = tlocdat1;        
        }else if(iswriting1 == true){
          //Serial.print(char(incomingbyte1));
          tlocdat1 += (char)incomingbyte1;  
        }
      }
      if (Serial2.available() > 0) {
        incomingbyte2 = Serial2.read();
        //Serial.print(char(incomingbyte2));
        if (incomingbyte2 == 's'){
          iswriting2 = true;
          tlocdat2 = "";
        }else if(incomingbyte1 == 'e'){
          iswriting2 = false;
          locdat2 = tlocdat1;        
        }else if(iswriting2 == true){
          //Serial.print(char(incomingbyte1));
          tlocdat2 += (char)incomingbyte1;  
        }
      }
      //Serial.println(locdat);
      sscanf(locdat1.c_str(), "%d, %d", &nir1, &pir1);
      sscanf(locdat2.c_str(), "%d, %d", &nir2, &pir2);

      Serial.print("locdat: ");
      Serial.print(String(locdat1));
      Serial.println(String(locdat2));
      
      
      if(pir1 > pir2){
         if(nir1 = 1){    //not good looking code because posbile wrong wireing
          degwhere = 0;      
         }else if(nir1 = 2){
          degwhere = 22.5;
         }else if(nir1 = 3){
          degwhere = 45;
         }else if(nir1 = 4){
          degwhere = 67.5;
         }else if(nir1 = 5){
          degwhere = 90;
         }else if(nir1 = 6){
          degwhere = 112.5;
         }else if(nir1 = 7){
          degwhere = 135;
         }else if(nir1 = 8){
          degwhere = 157.5;
         }
      }else{     
         if(nir2 = 1){
          degwhere = 180;
         }else if(nir2 = 2){
          degwhere = 202.5;
         }else if(nir2 = 3){
          degwhere = 225;
         }else if(nir2 = 4){
          degwhere = 247.5;
         }else if(nir2 = 5){
          degwhere = 270;
         }else if(nir2 = 6){
          degwhere = 292.5;
         }else if(nir2 = 7){
          degwhere = 315; 
         }else if(nir2 = 8){
          degwhere = 337.5; 
         }
      }

      Serial.print("Ball is at ");
      Serial.print(degwhere);
      Serial.println(" degrees.");
      drive(75, degwhere);
      delay(1);
    }
  }else{
    Serial.println("softPWR is off, waiting");
    delay(100);  
  }
}

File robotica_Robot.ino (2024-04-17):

/**
MIT License

Copyright (c) 2022 Abel Tim

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
 */

 // Code for rbc soccer robot
 //librarys
#include "Wire.h"                 //https://www.arduino.cc/reference/en/language/functions/communication/wire/
#include "Adafruit_TCS34725.h"    //https://github.com/adafruit/Adafruit_TCS34725
#include <SparkFunSX1509.h>       //https://learn.sparkfun.com/tutorials/sx1509-io-expander-breakout-hookup-guide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

#define PCAADDR 0x70              //i2c addres for i2c multiplexer https://learn.adafruit.com/adafruit-tca9548a-1-to-8-i2c-multiplexer-breakout/arduino-wiring-and-test

Adafruit_TCS34725 tcs = Adafruit_TCS34725(TCS34725_INTEGRATIONTIME_614MS, TCS34725_GAIN_1X); //collor sensor values


//IR sensors and multiplexer
const byte SX1509_ADDRESS = 0x3E; // SX1509 I2C address
SX1509 io;                        // Create an SX1509 object to be used throughout
const byte SX1509_IR_SENS1 = 1; // ir sens 1 to SX1509's pin 1
const byte SX1509_IR_SENS2 = 2; // ir sens 2 to SX1509's pin 2
const byte SX1509_IR_SENS3 = 3; // ir sens 3 to SX1509's pin 3
const byte SX1509_IR_SENS4 = 4; // ir sens 4 to SX1509's pin 4
const byte SX1509_IR_SENS5 = 5; // ir sens 5 to SX1509's pin 5
const byte SX1509_IR_SENS6 = 6; // ir sens 6 to SX1509's pin 6

int ir1 = 1; // IR sensor 1
int ir2 = 2; // IR sensor 2
int ir3 = 3; // IR sensor 3
int ir4 = 4; // IR sensor 4
int ir5 = 5; // IR sensor 5
int ir6 = 6; // IR sensor 6

//color sensors vars
int r1 = 1;
int g1 = 1;
int b1 = 1;
int r2 = 1;
int g2 = 1;
int b2 = 1;
int r3 = 1;
int g3 = 1;
int b3 = 1;
int r4 = 1;
int g4 = 1;
int b4 = 1;
int r5 = 1;
int g5 = 1;
int b5 = 1;
int r6 = 1;
int g6 = 1;
int b6 = 1;

//Motors
// motor one
int enA = 33;
int in1 = 2;
int in2 = 3;
// motor two
int enB = 36;
int in3 = 4;
int in4 = 5;
// motor three
int enC = 37;
int in5 = 7;
int in6 = 6;

int sp = 160; //speed
//variables used for motor controll
double dirA = 0.00;
double dirB = 0.00;
double dirC = 0.00;
double spdA = 0.00;
double spdB = 0.00;
double spdC = 0.00;
double dirrad = 0.00;

//code for i2c multiplexer
void pcaselect(uint8_t i) {
  if (i > 7) return;
  Wire.beginTransmission(PCAADDR);
  Wire.write(1 << i);
  Wire.endTransmission();  
}
//code for the motors
//for motor A
void Amove(int sped){
  Serial.print("moving A ");
  if (sped < 0) {
    digitalWrite(in1, LOW);
    digitalWrite(in2, HIGH);
    Serial.print("back");
  }
  else{
    digitalWrite(in1, HIGH);
    digitalWrite(in2, LOW);
    Serial.print("forward");
  } 
  Serial.print("with speed: ");
  sp = abs(sped); 
  analogWrite(enA, sp);
  Serial.println(sp);
}
//for motor B
void Bmove(int sped) {
  Serial.print("moving B ");
  if (sped < 0) {
    digitalWrite(in3, LOW);
    digitalWrite(in4, HIGH);
    Serial.print("back");
  } else {
    digitalWrite(in3, HIGH);
    digitalWrite(in4, LOW);
    Serial.print("forward");
  } 
  Serial.print("with speed: ");
  int sp = abs(sped);
  analogWrite(enB, sp);
  Serial.println(sp);
}
//for motor C
void Cmove(int sped) {
  Serial.print("moving C ");
  if (sped < 0) {
    digitalWrite(in5, LOW);
    digitalWrite(in6, HIGH);
    Serial.print("back");
  } else {
    digitalWrite(in5, HIGH);
    digitalWrite(in6, LOW);
    Serial.print("forward");
  } 
  Serial.print("with speed: ");
  int sp = abs(sped);
  analogWrite(enC, sp);
  Serial.println(sp);
}
//for omhi drive capabilities
void moveohmi(int speed, int direction)
{
  turnoff();

  double dirrad = (direction*71) / 4068;  
  Serial.println(dirrad);
  //vector ontb in x en y
  double x = sin(dirrad)*speed;
  double y = cos(dirrad)*speed;
  Serial.println((String)"x:"+x+" y:"+y);
  spdA = -0.5*x - sqrt(3)/2*y;
  spdB = x;
  spdC = -0.5*x + sqrt(3)/2*y;
  Amove(spdA);
  Bmove(spdB);
  Cmove(spdC);

  Serial.println(spdA);
  Serial.println(spdB);
  Serial.println(spdC);
  Serial.println();
  Serial.println();
}
//for turing
void turn(int speed){
  Serial.println("turn");
  analogWrite(enA, speed);
  analogWrite(enB, speed);
  analogWrite(enC, speed);
  digitalWrite(in1, HIGH);
  digitalWrite(in2, LOW);
  digitalWrite(in3, HIGH);
  digitalWrite(in4, LOW);
  digitalWrite(in5, HIGH);
  digitalWrite(in6, LOW);
}
//for moving forward
void forward(int speed){
  Serial.println("forward");
  analogWrite(enA, speed);
  analogWrite(enB, speed);
  analogWrite(enC, speed);
  digitalWrite(in1, LOW);
  digitalWrite(in2, LOW);
  digitalWrite(in3, HIGH);
  digitalWrite(in4, LOW);
  digitalWrite(in5, HIGH);
  digitalWrite(in6, LOW);
}
//for turning all engines off
void turnoff(){
  Serial.println("stop");
  analogWrite(enA, 0);
  analogWrite(enB, 0);
  analogWrite(enC, 0);
  digitalWrite(in1, LOW);
  digitalWrite(in2, LOW);
  digitalWrite(in3, LOW);
  digitalWrite(in4, LOW);
  digitalWrite(in5, LOW);
  digitalWrite(in6, LOW); 
}
//for finding the ball
void findball(int irs1, int irs2, int irs3, int irs4, int irs5, int irs6, int spedo){
  if (irs1 == 0){
    //0deg
    Bmove(-spedo);
    Cmove(spedo);
  }else if (irs2 == 0){
    //60deg
    Amove(-spedo);
    Cmove(spedo);
  }else if (irs3 == 0){
    //120deg
    Amove(-spedo);
    Bmove(spedo);
  }else if (irs4 == 0){
    //180deg
    Cmove(-spedo);
    Bmove(spedo);
  }else if (irs5 == 0){
    //240deg
    Cmove(-spedo);
    Amove(spedo);
  }
  else if (irs6 == 0){
    //300deg
    Bmove(-spedo);
    Amove(spedo);
  }
  else{
    //turn to search ball
    turn(spedo);
  }
}


  /**
    
  starting setup

**/
void setup() {
  // Motor setup
  pinMode(enA, OUTPUT);
  pinMode(enB, OUTPUT);
  pinMode(enC, OUTPUT);
  pinMode(in1, OUTPUT);
  pinMode(in2, OUTPUT);
  pinMode(in3, OUTPUT);
  pinMode(in4, OUTPUT);
  pinMode(in5, OUTPUT);
  pinMode(in6, OUTPUT);

  //sensor setup
  delay(1000);
  Wire.begin();
    
  Serial.begin(115200);
  Serial.println("\nPCAScanner ready!");
  for (uint8_t t=0; t<8; t++) {
    pcaselect(t);
    Serial.print("PCA Port #"); Serial.println(t);

    for (uint8_t addr = 0; addr<=127; addr++) {
      if (addr == PCAADDR) continue;

      Wire.beginTransmission(addr);
      if (!Wire.endTransmission()) {
        Serial.print("Found I2C 0x");  Serial.println(addr,HEX);
      }
    }
  }
  Serial.println("\ndone");
  Serial.println("mark1");
  if (io.begin(SX1509_ADDRESS) == false){
    Serial.println("Failed to communicate. Check wiring and address of SX1509.");
    while (1)
      ; // If we fail to communicate, loop forever.
  }
  io.pinMode(SX1509_IR_SENS1, INPUT);
  io.pinMode(SX1509_IR_SENS2, INPUT);
  io.pinMode(SX1509_IR_SENS3, INPUT);
  io.pinMode(SX1509_IR_SENS4, INPUT);
  io.pinMode(SX1509_IR_SENS5, INPUT);
  io.pinMode(SX1509_IR_SENS6, INPUT);
  Serial.println("mark2");

}

  /**
    
  starting loop 
  first collecting sensor data

**/
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

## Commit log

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2024-05-03 Commit message
    [CC6-1205SF-E.stp, EDI2CAP.CFG, chips.prt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]
2024-05-04 pcb boven gemaakt
    [pcb_onder.sch]
2024-05-04 pcb onder gemaakt
    [noname.kicad_pcb, pcb.sch, pcb_boven.sch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]
2024-06-03 add connect between teensy and openmv
    [pcb_boven.sch]
2024-06-05 add mcp
    [pcb_boven.sch]
2024-06-09 upd pcb
    [pcb_boven-B_Cu.gbr, pcb_boven-B_Mask.gbr, pcb_boven-B_Paste.gbr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]
2024-06-09 pcb_onder y
    [pcb_onder.kicad_pcb, pcb_onder.sch]
2024-06-11 3d file pcb
    [pcb_boven.kicad_pcb]
2024-06-22 update repo structure update poster add code flowchart
    [CC6-1203SR-E.stp, CC6-1205SF-E.stp, EDI2CAP.CFG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]
2024-06-22 remove OLD update poster
    [CC6-1203SR-E.stp, CC6-1205SF-E.stp, EDI2CAP.CFG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]
2024-06-23 git structure change poster
    [PCB Boven v2.f3d, PCB Boven v2.obj]
2024-06-24 lower pcb
    [pcb_onder.kicad_pcb, pcb_onder.sch, untitled.ply]
2024-06-25 3d file of pcb
    [PCB_onder.FCStd]
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2024-07-07 Motor driver code complette need to test/fix MCP23017
2024-07-22 change folder struct
    [82720Mold_SS.stp, BOM.ods, CC6-1203SR-E.STEP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]
2024-07-27 PCB schemas
    [Boven.kicad_sch, midden.kicad_sch, onder.kicad_sch]
2024-08-27 add full pcb schema
    [total_pcb.kicad_pcb, total_pcb.kicad_sch]
2024-09-05 nog lang niet klaar.
    [Robotica Volledige Robot3 v2.f3d]
2024-09-05 update pcb led
    [total_pcb.kicad_sch]
2024-10-07 Onder pcb kan gemaakt worden
    De rest moet nog uitgewerkt worden
    [Robotica Volledige Robot3 v4.f3z]
2024-10-07 Onder pcb kan gemaakt worden
    [Robotica Volledige Robot3 v5.f3z]
2024-10-08 UPDATE FOLDER STUCTURE
    MOET APARTE_PCB NOG VERWIJDERTEN WINDOWS HEEFT BEST VERGRENDELD
    [Boven.kicad_sch, Niew_boven.kicad_sch, freerouting.dsn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]
2024-10-13 Rename 3dfiles/Robotica Volledige Robot3 v5.f3z to 3dfiles/backups/Robotica Volledige Robot3 v5.f3z
    [Robotica Volledige Robot3 v5.f3z]
2024-10-14 laaste boutjes
    [Robotica Volledige Robot3 v13.f3z]
2024-10-14 Rename 3dfiles/Robotica Volledige Robot3 v11.f3z to 3dfiles/backups/Robotica Volledige Robot3 v11.f3z
    [Robotica Volledige Robot3 v11.f3z]
2024-10-14 kleine aanpassing op vorige aanpassingen
    [Robotica Volledige Robot3 v15.f3z]
2024-10-14 Rename 3dfiles/Robotica Volledige Robot3 v13.f3z to 3dfiles/backups/Robotica Volledige Robot3 v13.f3z
    [Robotica Volledige Robot3 v13.f3z]
2024-10-18 midden bijna klaar
    [midden.kicad_pcb]
2024-10-18 alleen solinoid nog
    [midden.kicad_pcb]
2024-10-19 solenoid gaten
    [Robotica Volledige Robot3 v16.f3z]
2024-10-19 Rename 3dfiles/Robotica Volledige Robot3 v15.f3z to 3dfiles/backups/Robotica Volledige Robot3 v15.f3z
    [Robotica Volledige Robot3 v15.f3z]
2024-10-19 Rename 3dfiles/Robotica Volledige Robot3 v15.stl to 3dfiles/backups/Robotica Volledige Robot3 v15.stl
    [Robotica Volledige Robot3 v15.stl]
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2024-11-01 schroef geaard
    moet nog onderste schroef
    [boven.kicad_pcb, boven.kicad_sch, midden.kicad_pcb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]
2024-11-04 Rename 3dfiles/Robotica Volledige Robot3 v16.f3z to 3dfiles/backups/Robotica Volledige Robot3 v16.f3z
    [Robotica Volledige Robot3 v16.f3z]
2024-11-04 Rename 3dfiles/Robotica Volledige Robot3 v16.stl to 3dfiles/backups/Robotica Volledige Robot3 v16.stl
    [Robotica Volledige Robot3 v16.stl]
2024-11-04 Rename 3dfiles/Robotica Volledige Robot3 v17.f3z to 3dfiles/backups/Robotica Volledige Robot3 v17.f3z
    [Robotica Volledige Robot3 v17.f3z]
2024-11-04 Rename 3dfiles/Robotica Volledige Robot3 v17.stl to 3dfiles/backups/Robotica Volledige Robot3 v17.stl
    [Robotica Volledige Robot3 v17.stl]
2024-11-06 pcb pre autoroute upload
    [PCBondermesh.3mf, PCBondermesh.stl, freerouting.dsn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]
2024-11-06 Onderste mesh veranderd
    [Robotica Volledige Robot3 v19.f3z]
2024-11-06 Rename 3dfiles/Robotica Volledige Robot3 v18.f3z to 3dfiles/backups/Robotica Volledige Robot3 v18.f3z
    [Robotica Volledige Robot3 v18.f3z]
2024-11-06 Rename 3dfiles/Robotica Volledige Robot3 v18.stl to 3dfiles/backups/Robotica Volledige Robot3 v18.stl
    [Robotica Volledige Robot3 v18.stl]
2024-11-07 af ready to check
    [freerouting.dsn, onder (1).kicad_pcb]
2024-12-19 Create verbeterde code door chatgpt
    ik heb de code in chat gestopt en heeft mij dit terug geschreven, kunnen we hier iets mee?
2025-03-20 issue 15 should be fixed
    [CODE.ino]
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2025-03-21 fix PWM
2025-03-26 Update and rename 3dfiles/RoboCupJunior SoccerField 2020.step to 3dfiles/oud/RoboCupJunior SoccerField 2020.step
    [RoboCupJunior SoccerField 2020.step]
2025-03-26 Rename 3dfiles/Robot V3.1 concept v3.f3z to 3dfiles/oud/Robot V3.1 concept v3.f3z
    [Robot V3.1 concept v3.f3z]
2025-03-26 Rename 3dfiles/Robotica Volledige Robot3 v29.f3z to 3dfiles/oud/Robotica Volledige Robot3 v29.f3z
    [Robotica Volledige Robot3 v29.f3z]
2025-03-26 Rename 3dfiles/Robotica Volledige Robot3 v29.stl to 3dfiles/oud/Robotica Volledige Robot3 v29.stl
    [Robotica Volledige Robot3 v29.stl]
2025-03-27 oude shit
    [Robotica Volledige Robot3 v11.f3z, Robotica Volledige Robot3 v13.f3z, Robotica Volledige Robot3 v15.f3z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]
2025-04-24 sim for omni drive
    [Soccer Field 2021 draft v2.step]
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2026-02-08 created PID and it better fucking works
    [Issue: X]
    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
2026-02-08 im a idiot
    had m1encSP to < 0 give error but a motor can also be not moving no < 0 so
